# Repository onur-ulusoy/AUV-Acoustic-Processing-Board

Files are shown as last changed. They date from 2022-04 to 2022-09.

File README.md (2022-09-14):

# Acoustic Processing Board (APB) Hardware

The Acoustic Processing Board (APB) is a specialized hardware project devoted to processing underwater acoustic signals, captured via hydrophones. This repository houses the electronic design and hardware specifications needed to construct or adapt the APB. Serving as a crucial tool for underwater exploration, navigation, and communication, the APB stands as a testament to innovative engineering solutions. This project is developed for ITU AUV Team.

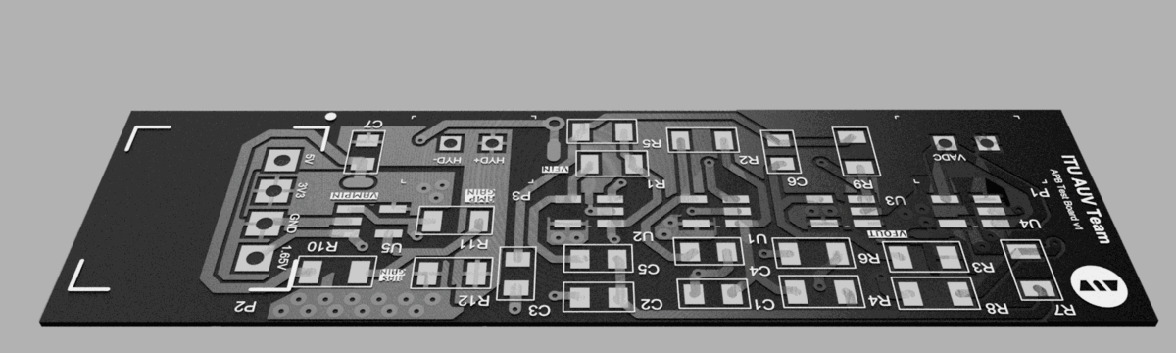
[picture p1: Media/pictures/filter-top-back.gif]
filter-board
<picture>    </picture>

<p align="center"><em >APB Filter Test Board</em></p>

<picture>   dash </picture>

<p align="center">
    <a href="https://auv.itu.edu.tr/">
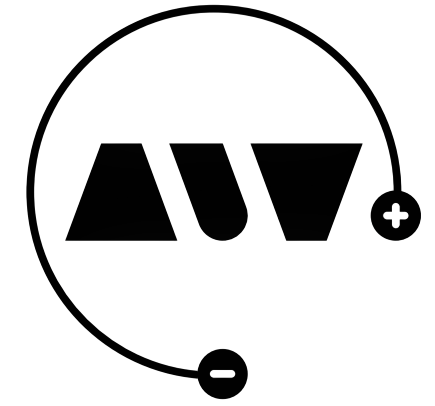
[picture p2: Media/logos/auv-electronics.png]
        
    </a>
</p>

<p align="center"><em >AUV Electronics 2022</em></p>

<picture>   dash </picture>

<p align="center">
    <a href="https://auv.itu.edu.tr/">
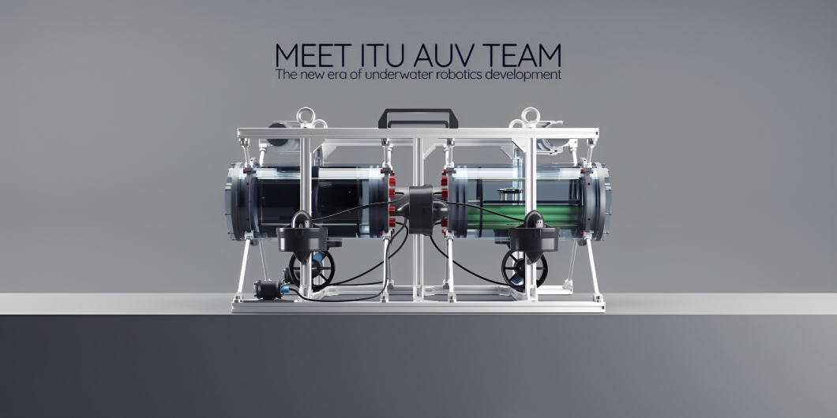
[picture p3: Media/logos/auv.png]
        
    </a>
</p>

<picture>   dash </picture>

<p align="center">
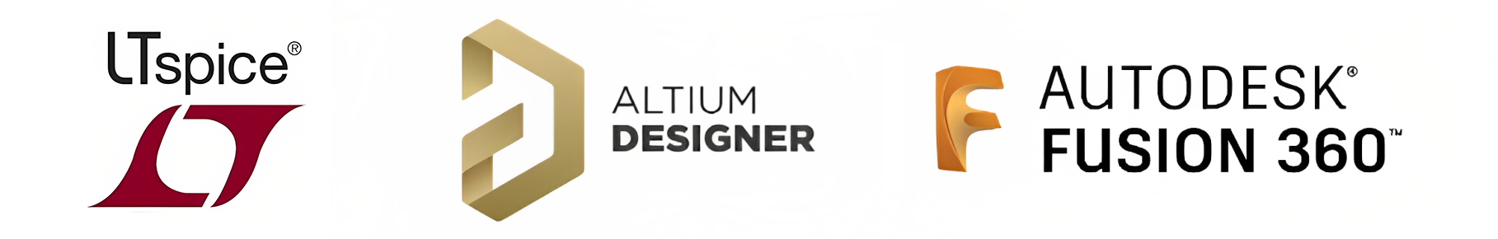
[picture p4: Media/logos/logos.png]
    
</p>

<picture>   dash </picture>

## Table of Contents
- [Acoustic Processing Board (APB) Hardware](#acoustic-processing-board-apb-hardware)
  - [Table of Contents](#table-of-contents)
  - [Project Description](#project-description)
  - [Electronics Design](#electronics-design)
    - [Hydrophone Biasing](#hydrophone-biasing)
    - [Pre-Amplification](#pre-amplification)
    - [6 Pole Butterworth Bandpass Filter](#6-pole-butterworth-bandpass-filter)
    - [Analog Power Supply](#analog-power-supply)
    - [ADC Buffering](#adc-buffering)
  - [Simulation](#simulation)
  - [Filter Test Board](#filter-test-board)
    - [Layer Structure](#layer-structure)
    - [Manufacturing](#manufacturing)
  - [Digital Part](#digital-part)
  - [Technologies Used](#technologies-used)
  - [License](#license)
  - [Project Timeline](#project-timeline)
  - [Gallery](#gallery)

## Project Description

The Acoustic Processing Board (APB) is a pivotal development in the field of Autonomous Underwater Vehicles (AUVs), designed to accurately detect the positions of underwater objects. To optimize performance, APB is split into two distinct parts: an analog PCB and a digital PCB.

The focus of this repository is the analog PCB, which primarily serves as a bandpass filter for frequencies between 25 and 40kHz. This PCB is designed to filter incoming signals from hydrophones before they are passed onto the digital component of the APB. The board was meticulously designed and simulated using LTspice software, featuring components from Analog Devices. The physical layout of the PCB was then accomplished using Altium Designer.

In addition to the analog PCB, there is a complementary digital PCB. This board is responsible for processing the filtered signals from three hydrophones to determine the location of objects underwater. It employs Fast Fourier Transform (FFT) algorithms for signal processing, and is powered by an STM32 microcontroller.

In the interest of thorough testing and performance optimization, the first iteration of the filter PCB was designed for a single hydrophone. This approach enables focused testing on the filtering capabilities, allowing for incremental improvements and fine-tuning of the board's performance before scaling to a three-hydrophone system.

The APB is a testament to innovative design, offering a unique approach to signal processing for AUVs. It represents a significant contribution to our understanding and exploration of underwater environments. We encourage you to explore the repository, understand the design, and contribute to the ongoing development of this cutting-edge technology.

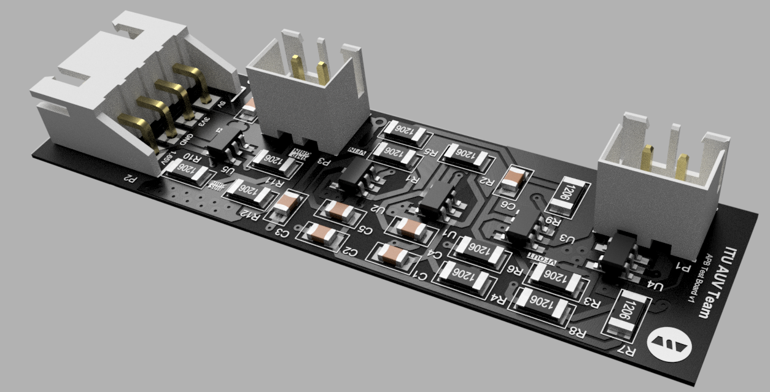
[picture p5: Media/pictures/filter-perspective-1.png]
filter-board
<picture>    </picture>

## Electronics Design

The APB Analog's design is a combination of intricate electronic engineering concepts and high-precision layout work. For an in-depth understanding of its composition, be sure to check the [Full schematics](/LTSpice_Simulation/Full%20Schematic.pdf) and [PCB Schematic Sheets](/Schematic%20Sheets/) These documents not only delineate the arrangement and interconnectivity of the board's components, but also offer insightful details about their specific roles and functionalities. Whether you're interested in the bandpass filtering process, power distribution, or the input/output interfaces, the schematic sheets hold the key to understanding the APB Analog's operational architecture.

### Hydrophone Biasing 

Hydrophone biasing is the first stage in our APB design, and it's vital to the overall functionality of the system. For each of the three hydrophones, a Vhyd- and Vhyd+ and Vcc are the inputs, while Vampin is the output. Importantly, Vhyd- is grounded. This arrangement ensures the correct biasing of the hydrophones, setting the correct operating point for each device and allowing for the effective conversion of underwater acoustic signals into electrical signals.

<p align="center">
    <a>
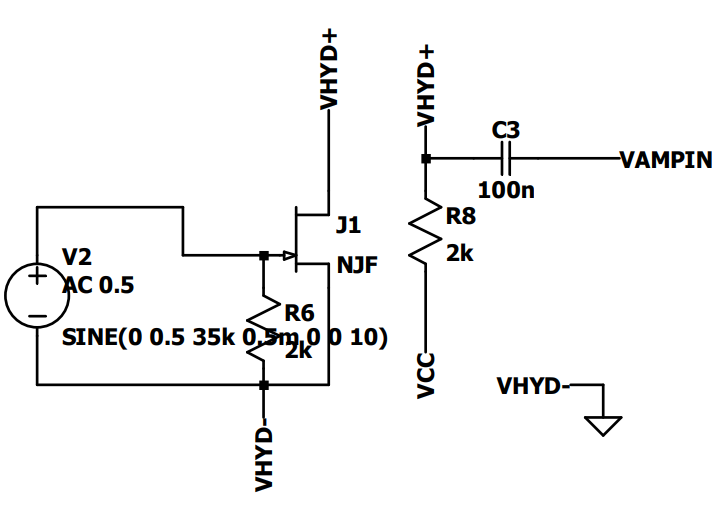
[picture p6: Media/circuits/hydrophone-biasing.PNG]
        
    </a>
</p>

### Pre-Amplification

The pre-amplification stage is another essential component of our APB design, ensuring that the electrical signals produced by the hydrophones are amplified adequately for further processing. This stage also employs three separate units, one for each hydrophone. Vampin is used as the input, while Vfin serves as the output. The pre-amplifier is driven by a high precision op-amp, ensuring low-noise amplification and thereby enhancing the clarity and resolution of the captured signals.

<p align="center">
    <a>
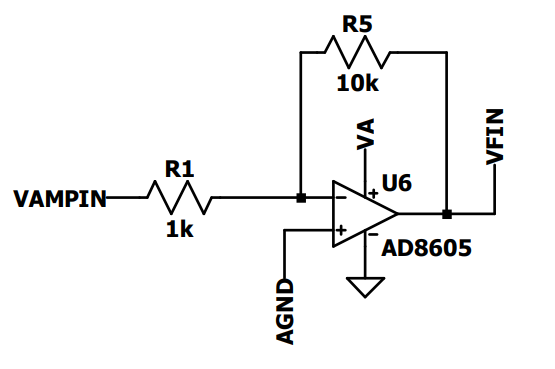
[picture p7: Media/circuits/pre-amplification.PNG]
        
    </a>
</p>

### 6 Pole Butterworth Bandpass Filter

To further process the amplified signals, we employ a 6-pole Butterworth bandpass filter. This filter is replicated three times, once for each hydrophone. The selection of this specific filter topology allows for a flat frequency response in the passband, and a fast roll-off rate, making it highly suitable for our signal processing needs. Appropriate capacitor and resistor values were determined using Analog Devices' application notes. The filter takes Vfin as an input and outputs a filtered signal, Vfout. Each operational amplifier in this stage is referenced with Agnd, which is supplied by the analog power supply circuit.

<p align="center">
    <a>
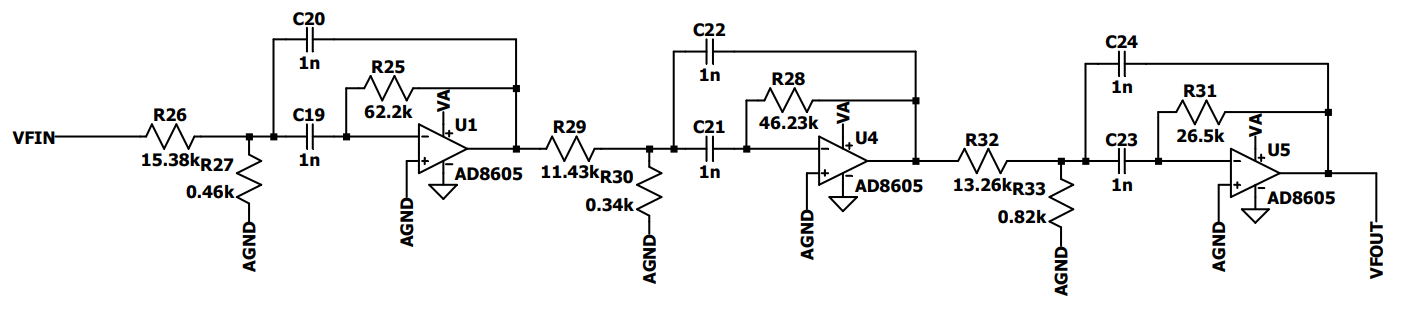
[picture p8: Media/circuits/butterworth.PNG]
        
    </a>
</p>

### Analog Power Supply

The analog power supply is an integral part of our design. Va is the input, and Agnd is the output. This unit provides the necessary power for all analog sections of the APB. Va and Agnd form the positive and negative poles of the op-amp in the other circuits. By generating a stable and low-noise power supply, this circuit ensures that the operational amplifiers and other analog components function optimally, minimizing signal distortion and maintaining high signal-to-noise ratios.

<p align="center">
    <a>
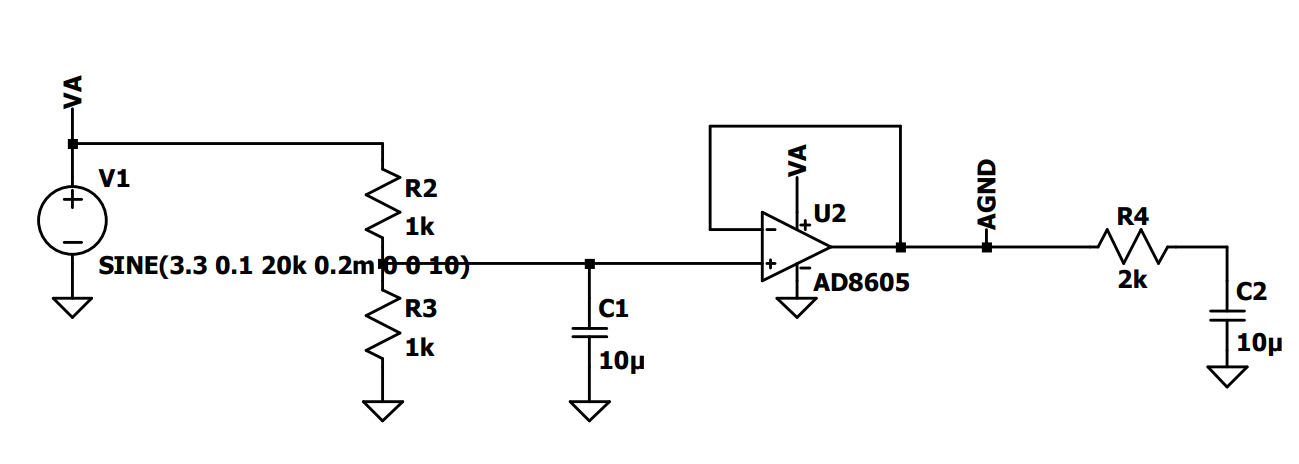
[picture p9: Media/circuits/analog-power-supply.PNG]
        
    </a>
</p>

### ADC Buffering

ADC buffering serves as the bridge between the analog and digital domains of our APB design. This stage, replicated three times for each hydrophone, takes the filtered signal, Vfout, as input and provides Vadc as output. The buffer, a unity gain amplifier (1x amp), plays a critical role in this system. Its purpose is to isolate the preceding stages from the ADC load. This isolation prevents any impedance mismatch that could degrade the signal quality. By using a buffer, we ensure that the signals processed by the ADC reflect as closely as possible the filtered signals from the bandpass filter stage, enabling accurate digital representation of the original acoustic signals.

<p align="center">
    <a>
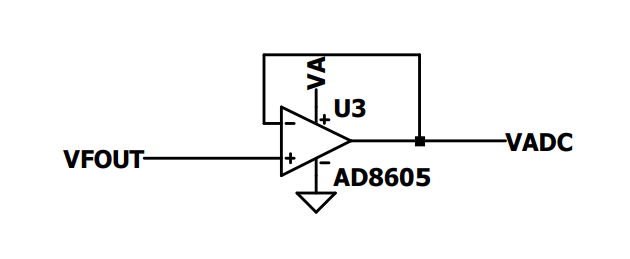
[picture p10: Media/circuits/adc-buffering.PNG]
        
    </a>
</p>

## Simulation

The APB analog subsystem was thoroughly simulated using LTspice, a high-performance SPICE simulator. LTspice offers a variety of capabilities, including enhanced SPICE and an integrated waveform viewer, making it a powerful tool for circuit analysis.

The simulation process involved the use of specific op-amps from Analog Devices. This choice of op-amps was driven by their favorable characteristics, such as low noise, high precision, and their performance within the frequency band of interest.

To ascertain the effectiveness of our 6-pole Butterworth bandpass filter design, we carried out frequency domain analysis. The results are demonstrated in the Bode plot below. As can be seen, the filter provides a passband for frequencies between 25 and 40 kHz, while attenuating frequencies outside this band. This frequency range was chosen specifically to match the operating range of the hydrophones and the acoustic signals they receive.

The simulation results validate the performance of the filter design and provide confidence in its ability to function as intended in the real-world application.

<p align="center">
    <a>
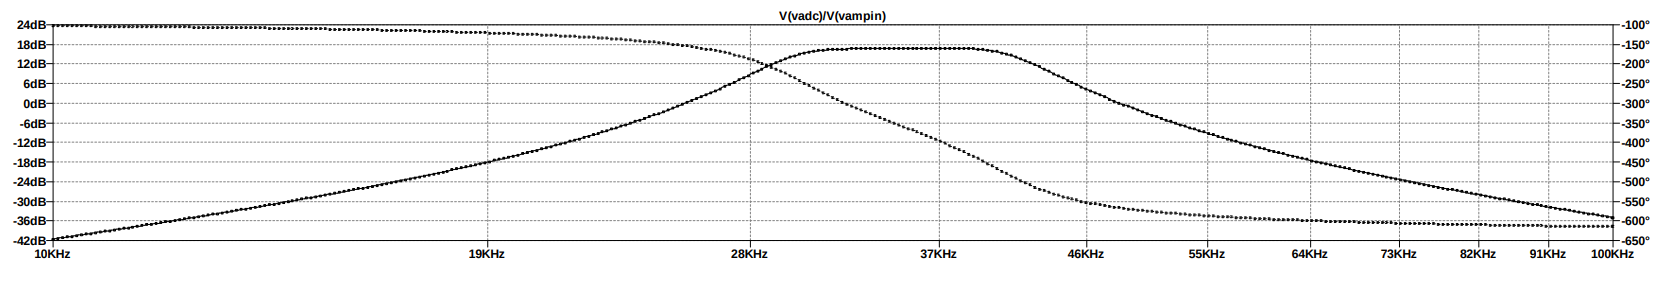
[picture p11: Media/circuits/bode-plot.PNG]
        
    </a>
</p>

## Filter Test Board

As part of our development and testing process, we designed a standalone PCB specifically for testing the performance of the filter stage and associated circuits. This board, known as the Filter Test Board, includes only the Butterworth filter, ADC buffering, and pre-amplification circuits, all for just a single hydrophone. 

The Filter Test Board contains crucial components from our original APB analog design that we aimed to test in isolation. We included the Butterworth filter stage, which is the centerpiece of our acoustic processing, to evaluate its frequency response and signal attenuation properties. The Pre-Amplification stage is also included, as it plays a crucial role in enhancing the signals coming from the hydrophone. Additionally, the ADC Buffering stage is incorporated into it. This stage is crucial for isolating the ADC load from the preceding stages, thereby preserving signal integrity. By focusing on these critical parts, the Filter Test Board allows us to verify the operation and performance of the main building blocks of our system without the interference of other elements. As a summary, It is basically includes cruical parts to process one hydrophone signal.

To aid in testing, we've added test points at key output locations like Vampin or Vfin as you can see in the below pcb picture, allowing for easy hook-up of measurement equipment such as oscilloscopes or signal generators. This way, we can inject signals and observe the system's response directly. We gave some voltages such as 1.65V directly to get rid of some power circuits.

Furthermore, we've chosen to use industrial-grade connectors for power supply and signal output. These connectors provide robust, reliable connections, crucial for both testing and eventual deployment.

The schematic diagrams for the Filter Test Board are available in the repository at [PCB Schematic Sheets](/Schematic%20Sheets/). Here, you'll find the full details of the circuits on the test board, providing a wealth of information for understanding and troubleshooting.

Below is top view of the Filter Test Board:

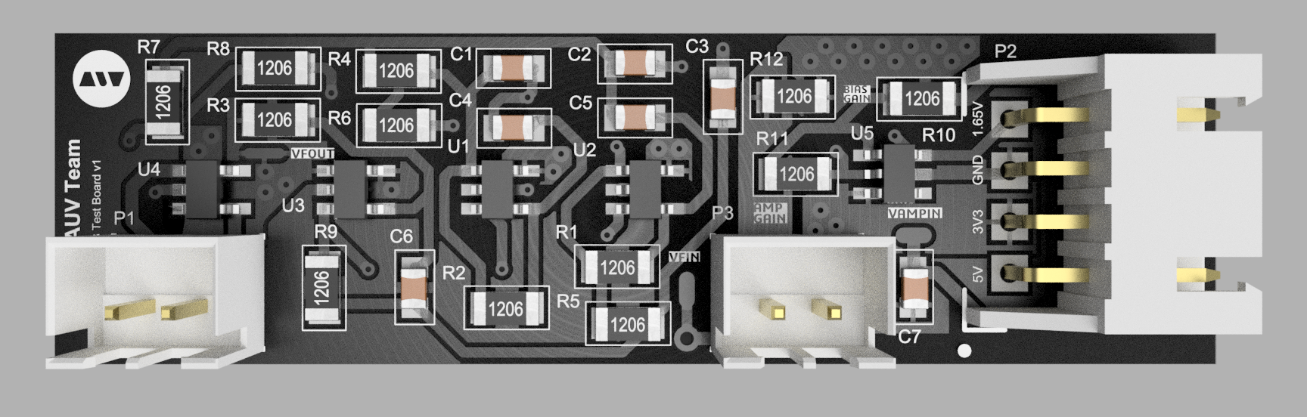
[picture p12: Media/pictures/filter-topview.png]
filter-board
<picture>    </picture>

### Layer Structure

This test version of the APB Analog PCB utilizes a two-layer structure, which has been chosen to simplify the initial stages of testing and troubleshooting. Once the test phase is complete and the design is deemed satisfactory, a transition to a four-layer PCB will take place for the original design. The change in layers not only accommodates the increased complexity of handling signals from three hydrophones simultaneously but also provides better noise isolation and improved signal integrity. Our filter test board's layers can be seen below.

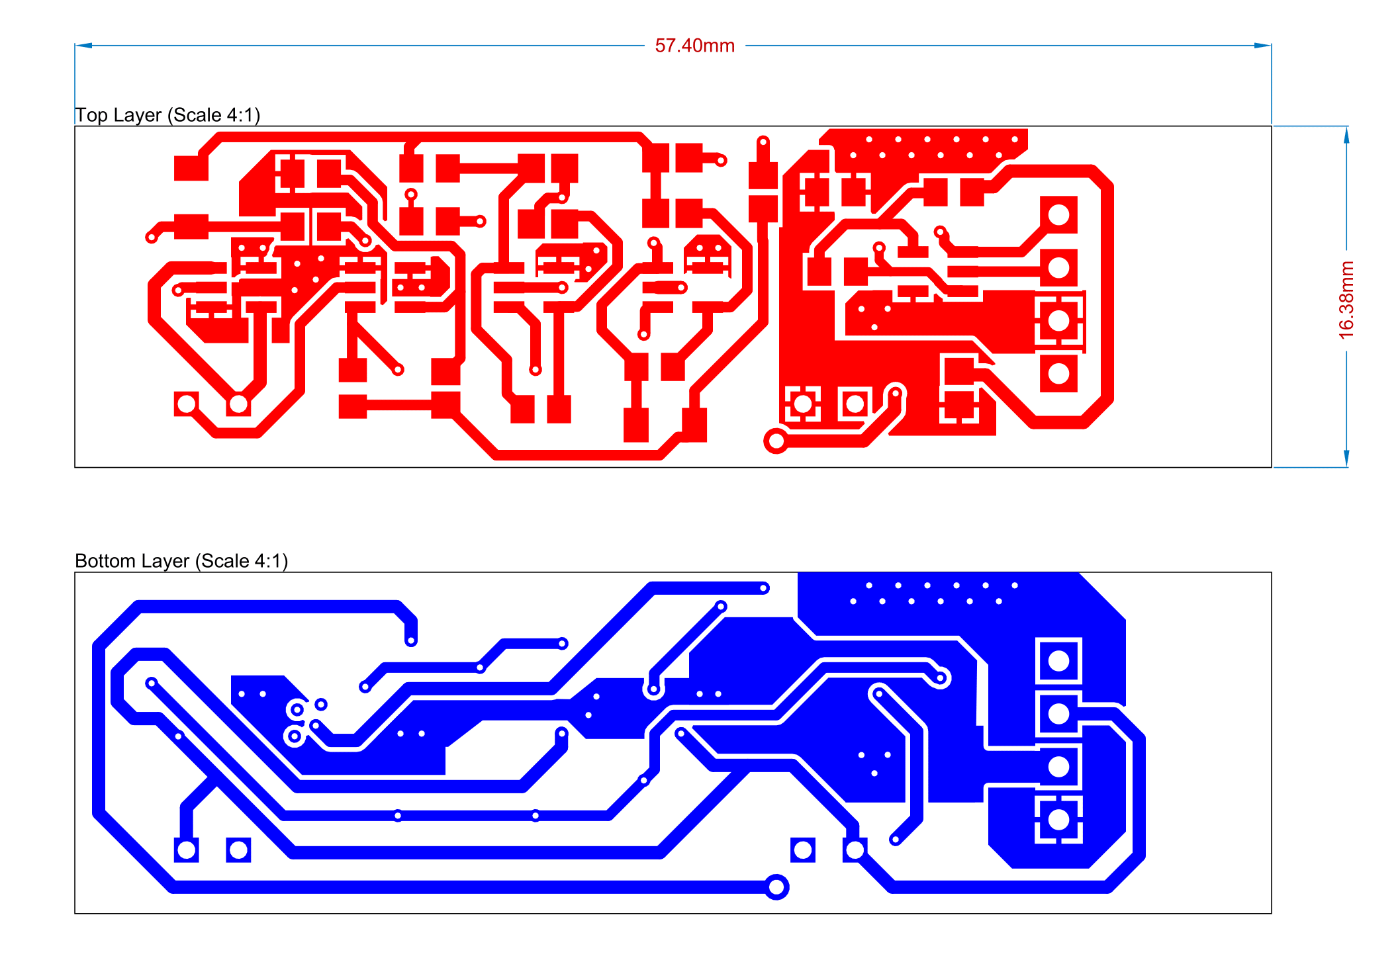
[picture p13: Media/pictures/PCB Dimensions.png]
<picture>    </picture>

To understand the depth of the board structure, component placement, and routing of traces, you can check out the [PCB file](/APB_Filter_Test_Board.PrjPcb). It offers a visual representation of the board, aiding in a better understanding of how the circuit's design translates into the physical realm. Keep in mind that this transition from a two-layer board to a four-layer one marks a critical milestone in the evolution of the APB project, embodying the growth from a test concept to a fully-realized, operational piece of hardware.

### Manufacturing

In order to ensure that our Filter Test Board design meets the specific manufacturing specifications of our chosen PCB manufacturer, we have employed the Design Rule Check (DRC) feature in Altium Designer. You can check the detailed report of this rule verification in the output files directory. 

The necessary Gerber files, which include the comprehensive manufacturing details needed to transform our electronic design into a tangible board, are compiled in the [Output](/Output%20Files/) directory.

To date, we have prototyped the Filter Test Board with our manufacturing partner, JLC PCB. Using the invaluable feedback and insights acquired from each iteration, we have continuously refined and improved the design, ensuring it's prepared for rigorous testing and eventual integration into the full Acoustic Processing Board system.

Below you can see some of the pictures of PCBs we manufactured:

<p align="center">
    <a>
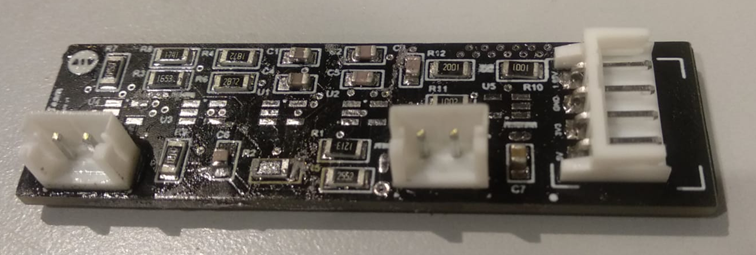
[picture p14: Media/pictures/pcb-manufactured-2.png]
        
    </a>
</p>

<p align="center">
    <a>
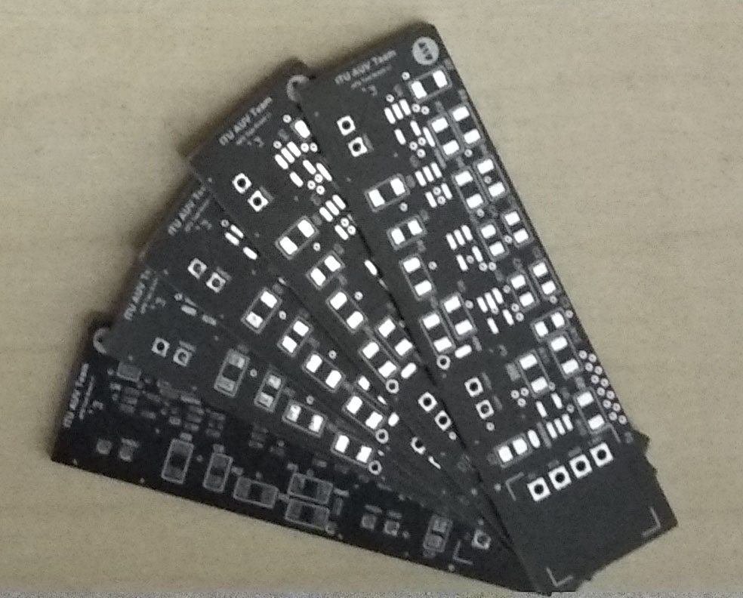
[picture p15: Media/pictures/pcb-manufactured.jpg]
        
    </a>
</p>

## Digital Part

The Digital Part represents the second crucial stage of the Acoustic Processing Board (APB). After the Analog Part processes the signals from the hydrophones, it's the responsibility of the Digital Part to receive these analog signals, evaluate them, and ultimately pinpoint the location of the acoustic source underwater.

One of the core operations conducted by the Digital Part involves Fast Fourier Transforms (FFTs). FFTs are a fundamental algorithm in signal processing and analysis, serving to convert a signal from the time domain (where each point represents amplitude at a specific time) into the frequency domain (where each point represents amplitude at a specific frequency). In the context of our APB, we use FFTs to identify the dominant frequencies present in the signals received from the hydrophones, which, when triangulated, can help determine the location of the underwater sound source.

The computational demands of these FFT operations are shouldered by an STM32H743 microcontroller. This powerful microcontroller is well-equipped to handle the processing needs of our board, boasting impressive capabilities, such as handling complex FFT operations and processing data from multiple hydrophones concurrently.

As of the time you're reading this, the development of the Digital Part is still underway. We are committed to achieving a robust, reliable digital signal processing system that effectively complements the analog processing capabilities of the APB. Stay tuned for updates as we continue to progress in this exciting project.

## Technologies Used

- **LTSpice:** At the outset of our design process, we used LTSpice, a high-performance SPICE simulator, for schematic capture and waveform viewer. This tool allowed us to simulate and analyze the behavior of our circuit designs, including the hydrophone biasing, pre-amplification, and filtering stages.

- **Analog Devices Web Applications:** To calculate the optimal values for our 6-Pole Butterworth Bandpass Filter components, we made use of the web applications provided by Analog Devices. These tools were indispensable in ensuring the correct operation of our filters, which play a critical role in the overall performance of the APB.

- **Altium Designer:** Our primary tool for crafting the complex layout of the PCBs was Altium Designer. Its powerful capabilities and intuitive interface allowed us to efficiently design, validate, and prepare the board's electronic components for manufacturing. Its extensive features facilitated the smooth handling of multi-layer board designs.

- **Eagle:** As an alternative to Altium Designer, we also used Autodesk Eagle for some aspects of the design process. Eagle offered us a simpler, more streamlined interface for initial design and testing stages, before transitioning to the more robust Altium Designer for finalizing the intricate multi-layer layout.

- **Fusion 360:** To manage the mechanical design and rendering of the APB, we used Autodesk Fusion 360. This powerful CAD/CAM tool not only allowed us to visualize and perfect the physical design of the board but also helped us ensure its compatibility within the AUV. The integration capabilities of Fusion 360 also facilitated seamless coordination with the mechanical team.

## License



This repository contains the design and documentation for the AUV Acoustic Processing Board, a project by the ITU AUV Team Electonics 2022.

**Licensor:** ITU AUV Team 2022 Electronics

This work is licensed under a [Creative Commons Attribution-NonCommercial-ShareAlike 4.0 International License](http://creativecommons.org/licenses/by-nc-sa/4.0/). You can view the full terms of the license in the [LICENSE](./LICENSE) file in this repository.

**Please note:** When using this project, you must give appropriate credit, including a link to the original GitHub repository: [https://github.com/onur-ulusoy/AUV-Acoustic-Processing-Board](https://github.com/onur-ulusoy/AUV-Acoustic-Processing-Board)

## Project Timeline

This Acoustic Processing Board (APB) project, a significant contribution to the 2022 Electronics Team of ITU AUV (Istanbul Technical University's Autonomous Underwater Vehicle), spanned from December 2021 to August 2022. 

In the initial design and simulation stages of the project, Onur Ulusoy and Sencer Yazıcı diligently worked to create an effective system for processing signals from underwater hydrophones. Their efforts involved comprehensive electronic design and meticulous simulation using LTSpice and Analog Devices' applications. 

Once the design was validated through simulation, the next stage of the project involved the physical realization of the APB. The Filter Test PCB, an essential component of the project, was designed, have manufactured, and typeset by Onur Ulusoy. This crucial testing PCB was brought to life using Altium Designer, with the manufacturing process carried out by JLCPCB. 

While the project was ongoing, thorough documentation was maintained by Onur Ulusoy. His efforts provided an accurate and detailed record of the project, documenting key design decisions, simulation results, and changes made during the PCB design and testing stages. 

As of the current timeline, the Digital Part of the APB, which is designed to receive and analyze the processed signals, is not yet completed. However, the successful development and testing of the APB's analog parts mark significant milestones towards the final goal. 

We are grateful for the invaluable guidance provided by Sencer Yazıcı throughout the development process. His expertise and mentorship played a crucial role in the success of this project. 

Throughout the duration of the Acoustic Processing Board (APB) project, we utilized Trello as our primary project management tool. Trello's intuitive interface and flexible features allowed us to plan, track, and coordinate our tasks effectively. By creating distinct cards for different tasks and using lists to represent different stages of our workflow, we were able to maintain a clear overview of our progress at all times. 

## Gallery

For a visual tour of the APB Filter Test Board PCB, you can explore our [gallery](https://onur-ulusoy.github.io/AUV-Acoustic-Processing-Board/Media/gallery.html). Here you'll find detailed images showcasing the design and implementation of the board.

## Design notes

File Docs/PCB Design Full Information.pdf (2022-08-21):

## 6 Pole Butterworth Bandpass Filter

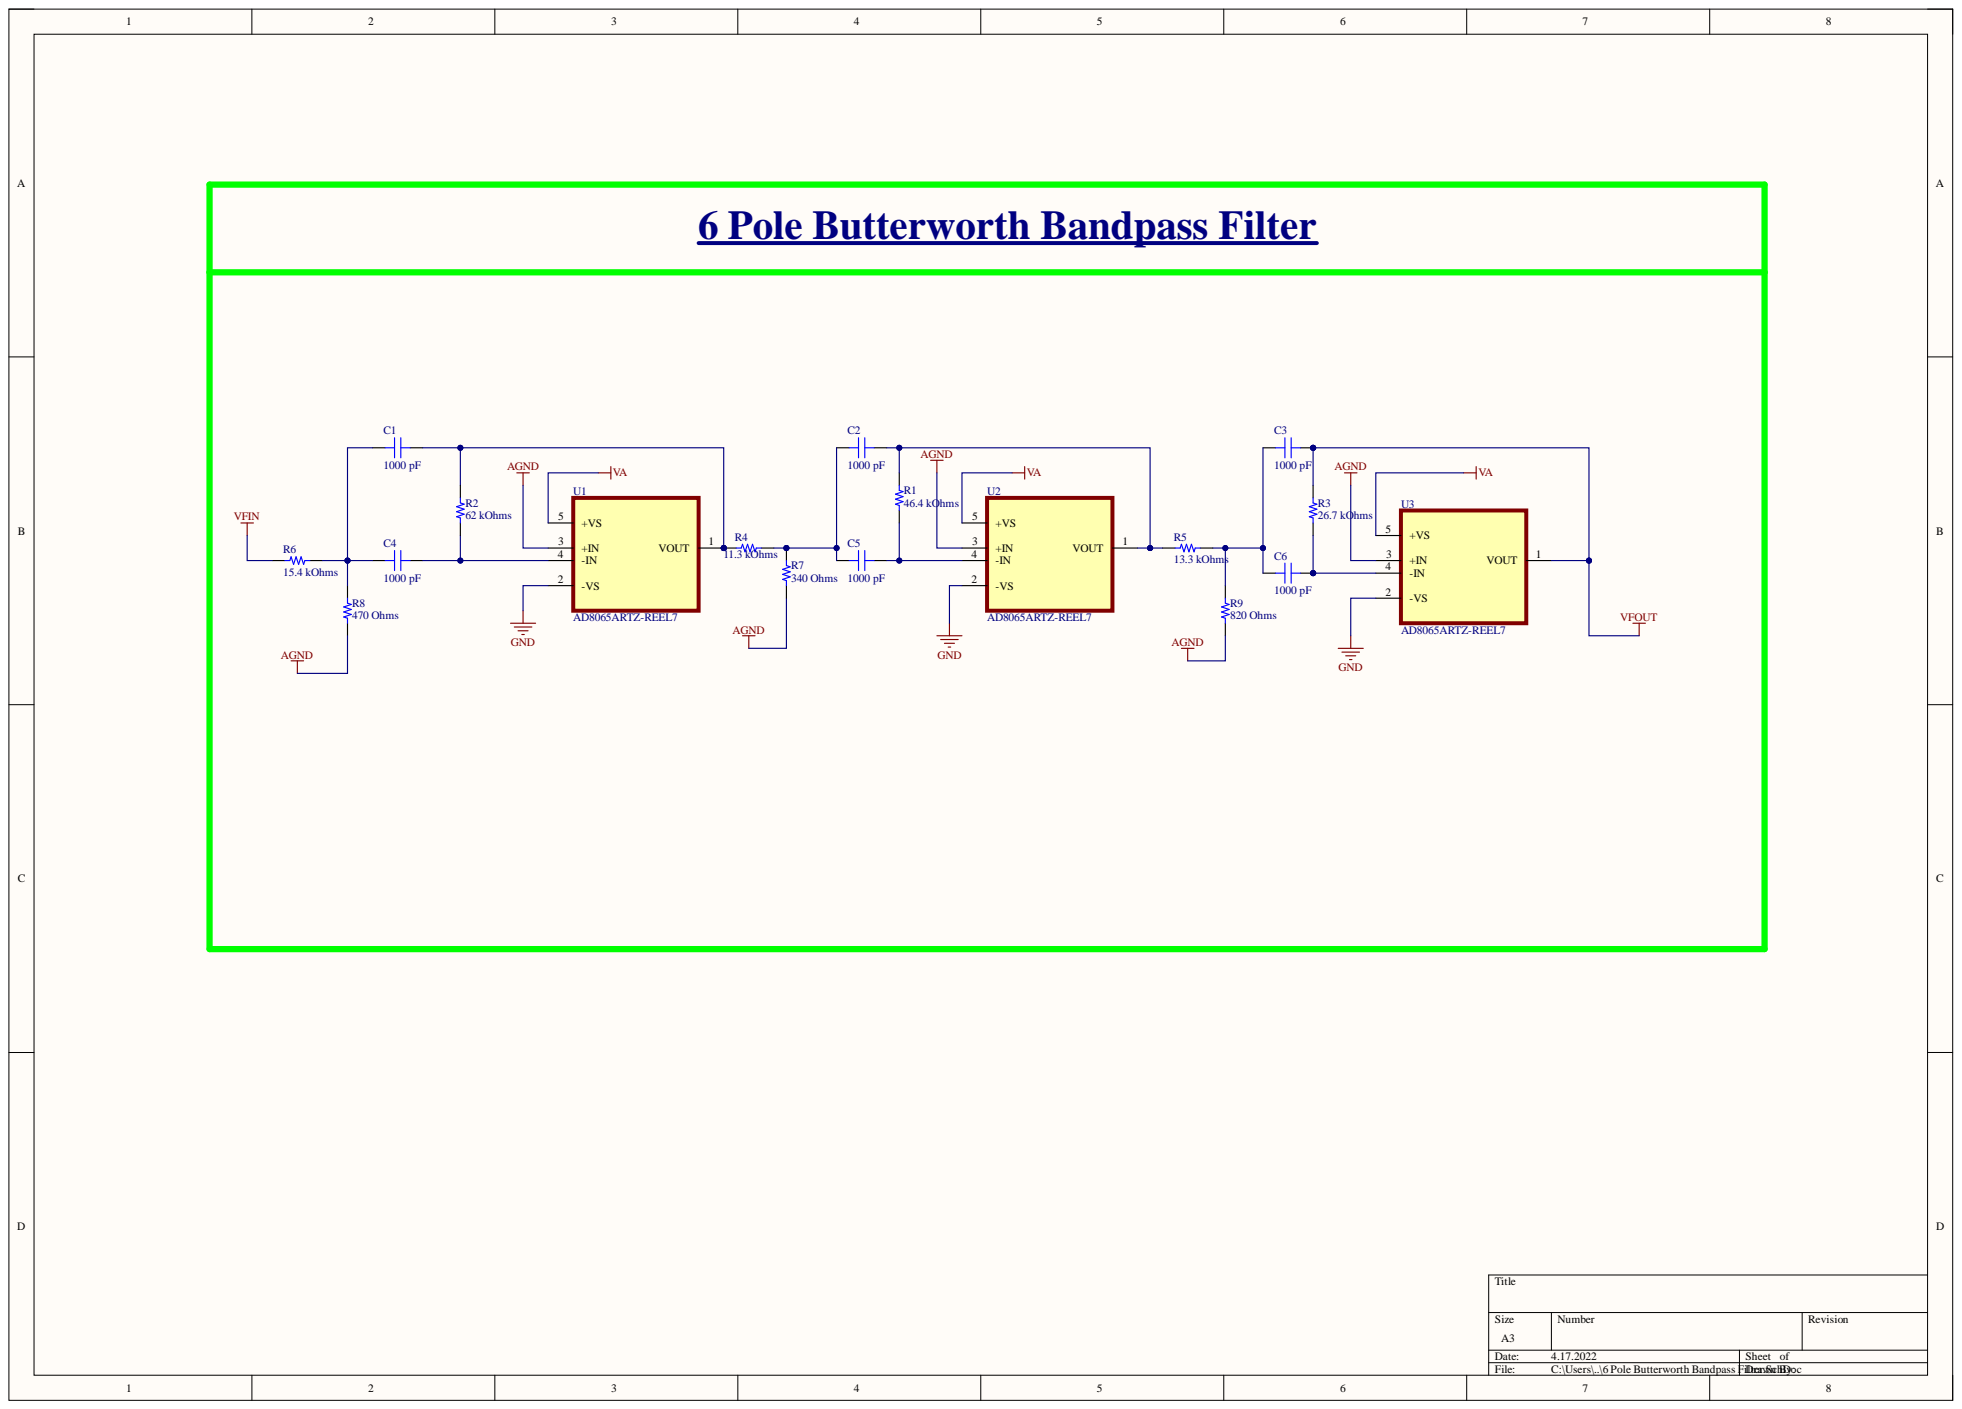
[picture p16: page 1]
Numbe; Revi; Dat; Sheet of; ser; \..\6 Pole; But; ter; wor; Bandpas; VFO; VFI; 11.3 kOhm; 15.4 kOhm; Ohm; 46.4 kOhm; 26.7 kOhm; 13.3 kOhm; 62 kOhm

s FiDltreraw.SchD n By:oc

# ADC Buffering

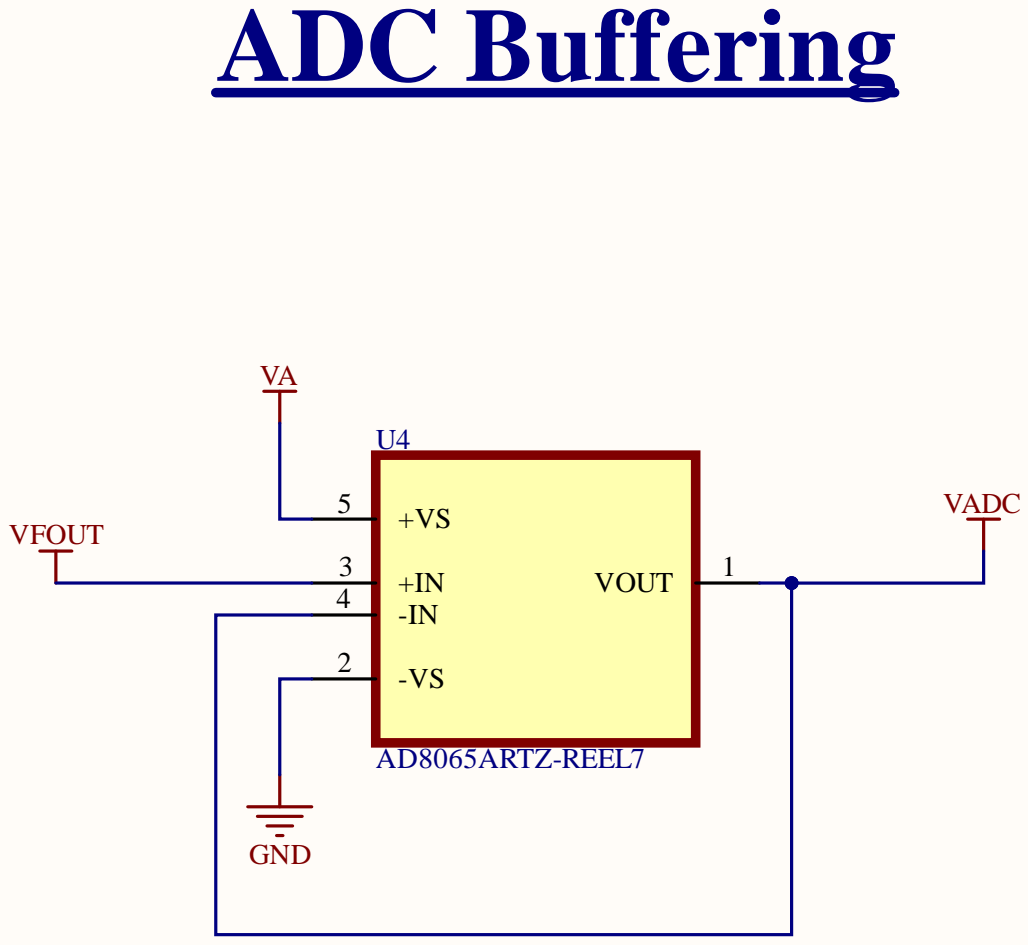
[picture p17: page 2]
Title; Size; Number; Revision; Date:; Sheet of; File:; C:\Users\..\ADC Buffering.SchDoc; Drawn By:; VOUT; AD8065ARTZ-REEL7; VFOUT; GND; VADC; PIU401; PIU402; PIU403; PIU404; PIU405; COU4

# Input-Output

### Pre Amp

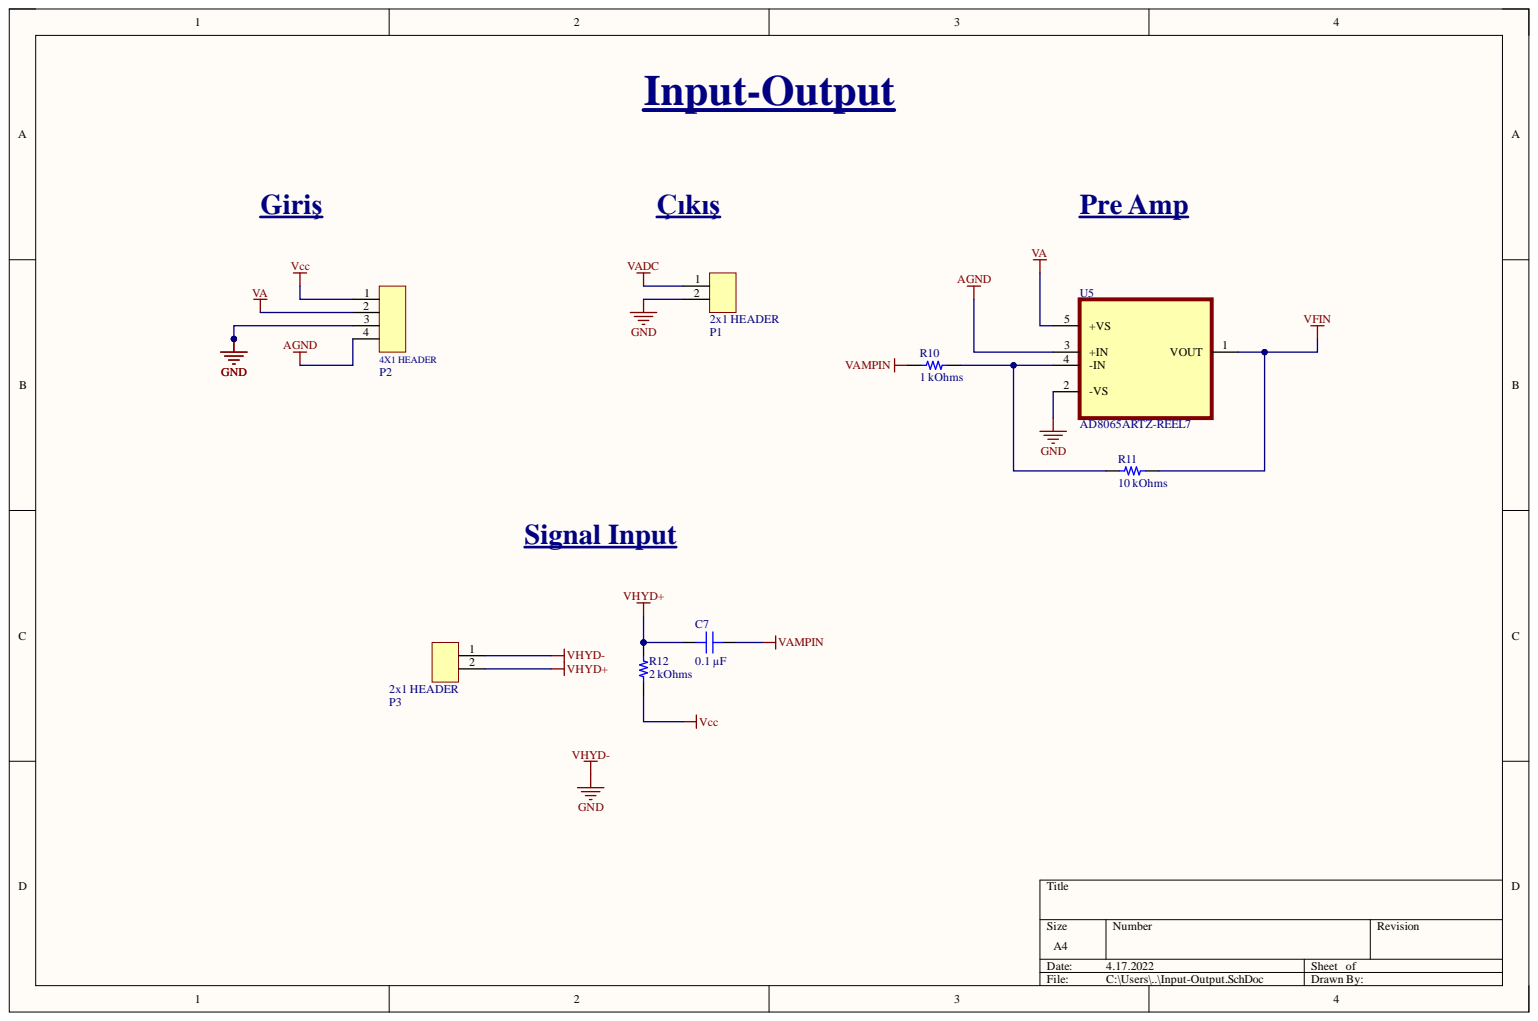
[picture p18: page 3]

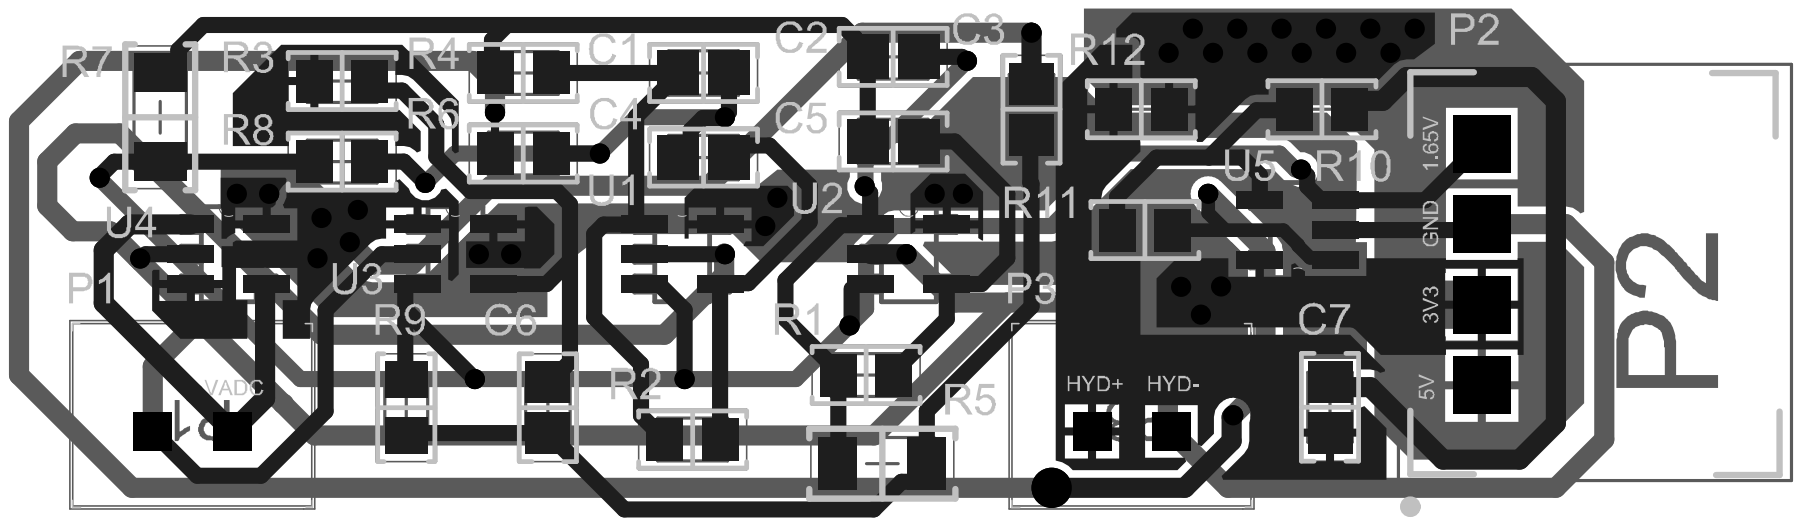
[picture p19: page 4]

Comment | Description | Designator | Footprint | LibRef | Quantity
1000 pF | CAP CER 1000PF 100V C0G 0805 | C1, C2, C3, C4, C5, C6 | CAP 0805_2012 | C2012C0G2A102J060 AA | 6
0.1 µF | CAP CER 0.1UF 50V X7R 0805 | C7 | CAP 0805_2012 | CC0805MRX7R9BB10 4 | 1
WIRE-TO BOARD WAFER, 2.5MM, 2 CO | Connector Header Through Hole 2 position 0.098" (2.50mm) | P1, P3 | 51025-02-0100-01 | 51025-02-0100-01 | 2
WIRE-TO BOARD HEADER, 2.5MM, 4 C | Wire-to Board Header, 2.5MM, 4 C | P2 | 51125-04-0200-01 | 51125-04-0200-01 | 1
46.4 kOhms | RES SMD 46.4K OHM 0.5% 1/8W 0805 | R1 | RES 0805_2012 | RT0805DRE0746K4L | 1
62 kOhms | RES SMD 62K OHM 0.1% 1/10W 0805 | R2 | RES 0805_2012 | CPF0805B62KE1 | 1
26.7 kOhms | RES SMD 26.7K OHM 1% 1/8W 0805 | R3 | RES 0805_2012 | ERJ-6ENF2672V | 1
11.3 kOhms | RES 11.3K OHM 1% 1/4W 0805 | R4 | RES 0805_2012 | RK73H2ATTD1132F | 1
13.3 kOhms | RES 13.3K OHM 1% 1/4W 1206 | R5 | RES 1206_3216 | RK73H2BTTD1332F | 1
15.4 kOhms | RES SMD 15.4K OHM 1% 1/8W 0805 | R6 | RES 0805_2012 | ERJ-6ENF1542V | 1
340 Ohms | RES SMD 340 OHM 1% 1/4W 1206 | R7 | RES 1206_3216 | ERJ-8ENF3400V | 1
470 Ohms | RES 470 OHM 1% 1/3W 0805 | R8 | RES 0805_2012 | CRGP0805F470R | 1
820 Ohms | RES 0805 820R 5% 125MW TC200 LOW | R9 | RES 0805_2012 | CR0805-JW-821EPF | 1
1 kOhms | RES SMD 1K OHM 5% 1/3W 0805 | R10 | RES 0805_2012 | CRGH0805J1K0 | 1
10 kOhms | RES 10K OHM 0.5% 1/8W 0805 | R11 | RES 0805_2012 | RNCF0805DTE10K0 | 1
2 kOhms | RES SMD 2K OHM 1% 0.4W 0805 | R12 | RES 0805_2012 | RCS08052K00FKEA | 1
AD8065ARTZ-REEL7 | Voltage Feedback Amplifier 1 Circuit Rail-to-Rail SOT-23-5 | U1, U2, U3, U4, U5 | SOT95P290X145-5N | AD8065ARTZ-REEL7 | 5

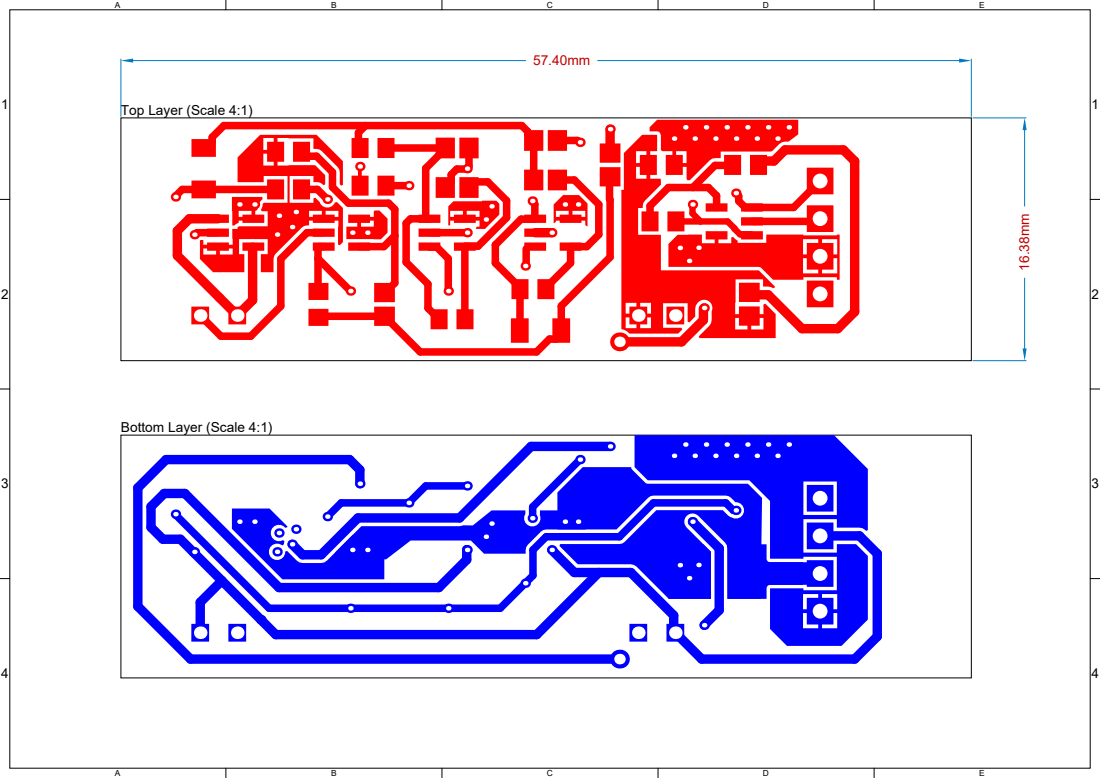
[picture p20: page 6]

Top Layer (Scale 4:1)

Bottom Layer (Scale 4:1)

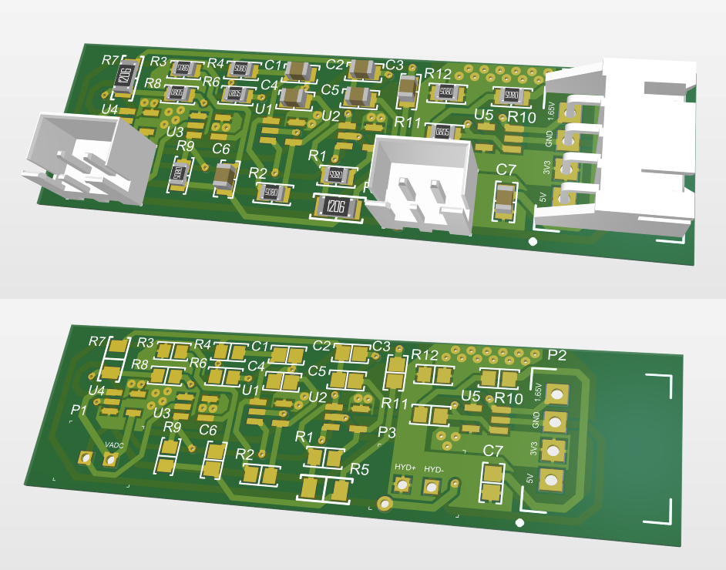
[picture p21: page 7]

### Dirençler

11.3k (Paket: 0805)

Digikey:

https://www.digikey.com/en/products/detail/koa-speer-electronicsinc/RK73H2ATTD1132F/10233627 (https://www.digikey.com/en/products/detail/koa-speer-electronics-inc/RK73H2ATTD1132F/10233627)

Özdisan:

https://ozdisan.com/passive-components/resistors/smt-smd-and-chip-resistors/0805S8F1132T5E

R340 (Paket: 1206)

Digikey:

https://www.digikey.com/en/products/detail/panasonic-electronic-components/ERJ-8ENF3400V/88773 (https://www.digikey.com/en/products/detail/panasonic-electronic-components/ERJ-8ENF3400V/88773)

Özdisan:

https://ozdisan.com/passive-components/resistors/smt-smd-and-chip-resistors/1206S4F3400T5E

62k (Paket: 0805)

Digikey:

https://www.digikey.com/en/products/detail/te-connectivity-passiveproduct/CPF0805B62KE1/2382068 (https://www.digikey.com/en/products/detail/te-connectivity-passive-product/CPF0805B62KE1/2382068)

Özdisan:

https://ozdisan.com/passive-components/resistors/smt-smd-and-chip-resistors/0805S8J0623T5E

15.4k Paket: (0805)

Digikey:

https://www.digikey.com/en/products/detail/ERJ-6ENF1542V/P15.4KCCT-ND/119315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 (https://www.digikey.com/en/products/detail/ERJ-6ENF1542V/P15.4KCCT-ND/119315?curr=usd)

Özdisan:

https://ozdisan.com/passive-components/resistors/smt-smd-and-chip-resistors/0805S8F1542T5E

R470 (Paket: 0805)

Digikey:

https://www.digikey.com/en/products/detail/CRGP0805F470R/A130473CT-ND/8578305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 (https://www.digikey.com/en/products/detail/CRGP0805F470R/A130473CT-ND/8578305?curr=usd)

Özdisan:

https://ozdisan.com/passive-components/resistors/smt-smd-and-chip-resistors/0805S8J0471TDE

46.4k (Paket: 0805)

Digikey:

https://www.digikey.com/en/products/detail/yageo/RT0805DRE0746K4L/1078715

Özdisan:

https://ozdisan.com/passive-components/resistors/smt-smd-and-chip-resistors/0805S8F4642T5E

13.3k (Paket: 1206)

Digikey:

https://www.digikey.com/en/products/detail/koa-speer-electronicsinc/RK73H2BTTD1332F/10236178 (https://www.digikey.com/en/products/detail/koa-speer-electronics-inc/RK73H2BTTD1332F/10236178)

Özdisan:

https://ozdisan.com/passive-components/resistors/smt-smd-and-chip-resistors/1206S4F1332T5E

R820 (Paket: 0805)

Digikey:

https://www.digikey.com/en/products/detail/bourns-inc/CR0805-JW-821EPF/8572952

Özdisan:

https://ozdisan.com/passive-components/resistors/smt-smd-and-chip-resistors/0805S8J0821T5E

26.7k (Paket: 0805)

Digikey:

https://www.digikey.com/en/products/detail/panasonic-electronic-components/ERJ-6ENF2672V/111557 (https://www.digikey.com/en/products/detail/panasonic-electronic-components/ERJ-6ENF2672V/111557)

Özdisan:

https://ozdisan.com/passive-components/resistors/smt-smd-and-chip-resistors/0805S8F2672T5E

1k (Paket: 0805)

Digikey:

https://www.digikey.com/en/products/detail/te-connectivity-passiveproduct/CRGH0805J1K0/2385524 (https://www.digikey.com/en/products/detail/te-connectivity-passive-product/CRGH0805J1K0/2385524)

Özdisan:

https://ozdisan.com/passive-components/resistors/smt-smd-and-chip-resistors/0805S8F1001T5E

10k (Paket: 0805)

Digikey:

https://www.digikey.com/en/products/detail/stackpole-electronics-inc/RNCF0805DTE10K0/1708247

Özdisan:

https://ozdisan.com/passive-components/resistors/smt-smd-and-chip-resistors/0805S8F1002T5E

2k (Paket: 0805)

Digikey:

https://www.digikey.com/en/products/detail/vishay-dale/RCS08052K00FKEA/5866986

Özdisan:

https://ozdisan.com/passive-components/resistors/smt-smd-and-chip-resistors/0805S8F2001T5E

### Kapasiteler

### 1 nF (Paket: 0805)

Digikey:

https://www.digikey.com/en/products/detail/C2012C0G2A102J060AA/445-2320-1-ND/789829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 (https://www.digikey.com/en/products/detail/C2012C0G2A102J060AA/445-2320-1-ND/789829?curr=usd)

Özdisan:

https://ozdisan.com/passive-components/capacitors/smt-smd-and-mlcccapacitors/CL21B102KBANNNC (https://ozdisan.com/passive-components/capacitors/smt-smd-and-mlcc-capacitors/CL21B102KBANNNC)

### 0.1 uF (Paket: 0805)

Digikey:

https://www.digikey.com/en/products/detail/CC0805MRX7R9BB104/311-4351-1-ND/8025440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 (https://www.digikey.com/en/products/detail/CC0805MRX7R9BB104/311-4351-1-ND/8025440?curr=usd)

Özdisan:

https://ozdisan.com/passive-components/capacitors/smt-smd-and-mlcccapacitors/CL21B104KCFNNNE (https://ozdisan.com/passive-components/capacitors/smt-smd-and-mlcc-capacitors/CL21B104KCFNNNE)

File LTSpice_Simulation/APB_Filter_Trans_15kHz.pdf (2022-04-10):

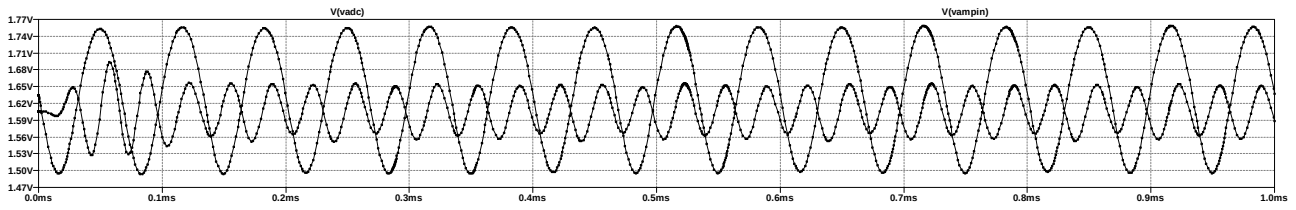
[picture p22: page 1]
V(vadc); V(vampin)

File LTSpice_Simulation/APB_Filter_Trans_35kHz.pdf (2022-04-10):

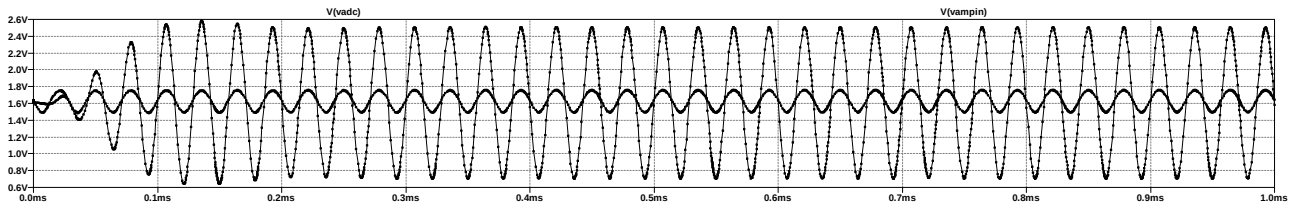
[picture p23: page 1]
V(vadc); V(vampin)

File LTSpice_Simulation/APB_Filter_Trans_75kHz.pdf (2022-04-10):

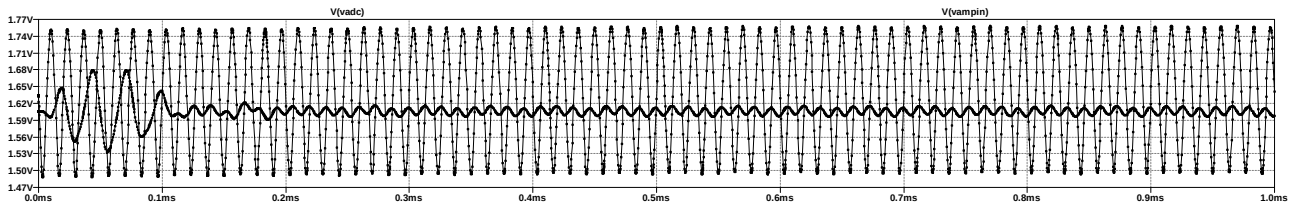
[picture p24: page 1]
V(vadc); V(vampin)

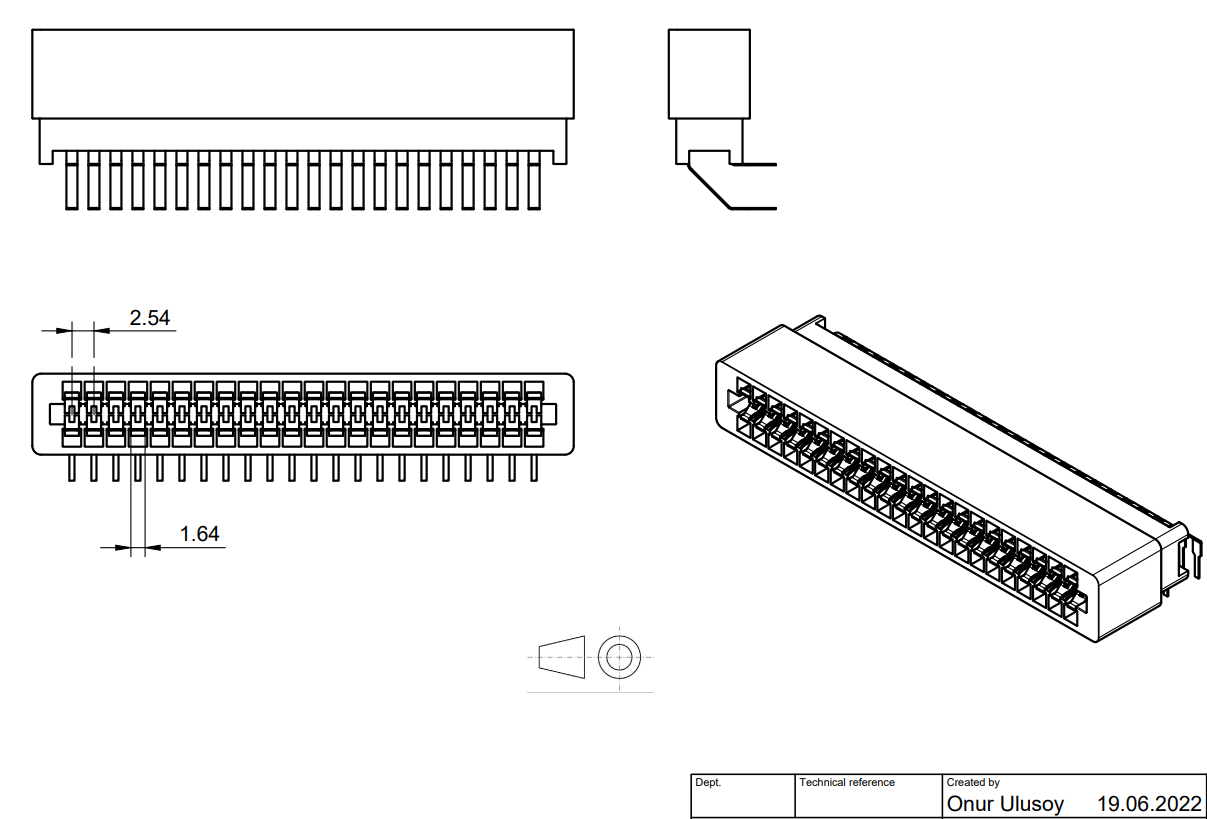
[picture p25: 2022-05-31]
Docs/EDGE PCB Connector P2.54mm 44pin 2 Rows Right Angle Drawing v3.PNG

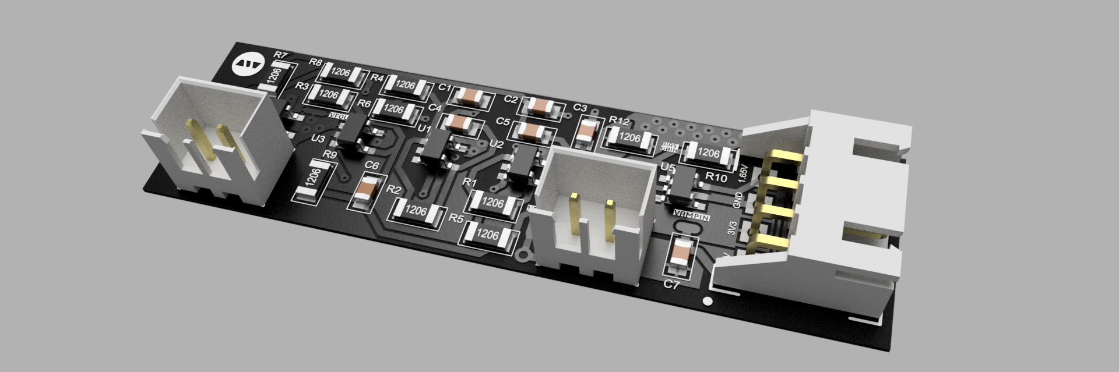
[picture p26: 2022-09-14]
Media/pictures/perspective-3.png

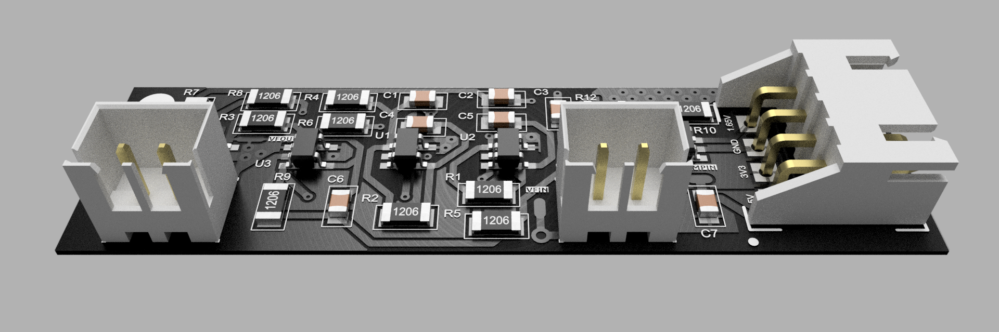
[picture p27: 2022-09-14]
Media/pictures/filter-top-front.png

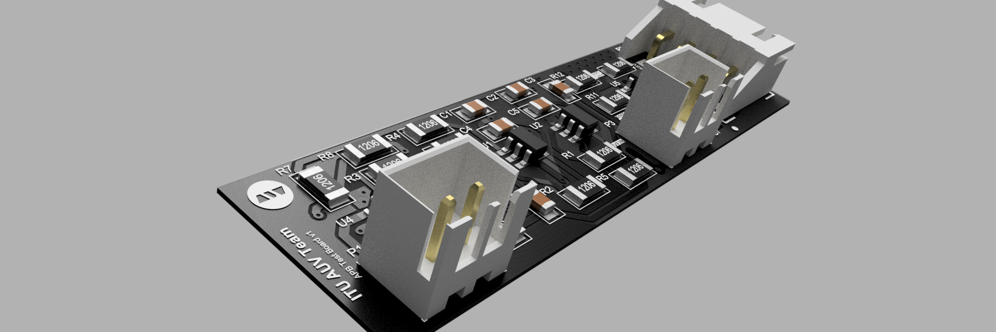
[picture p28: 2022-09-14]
Media/pictures/perspective-2.png

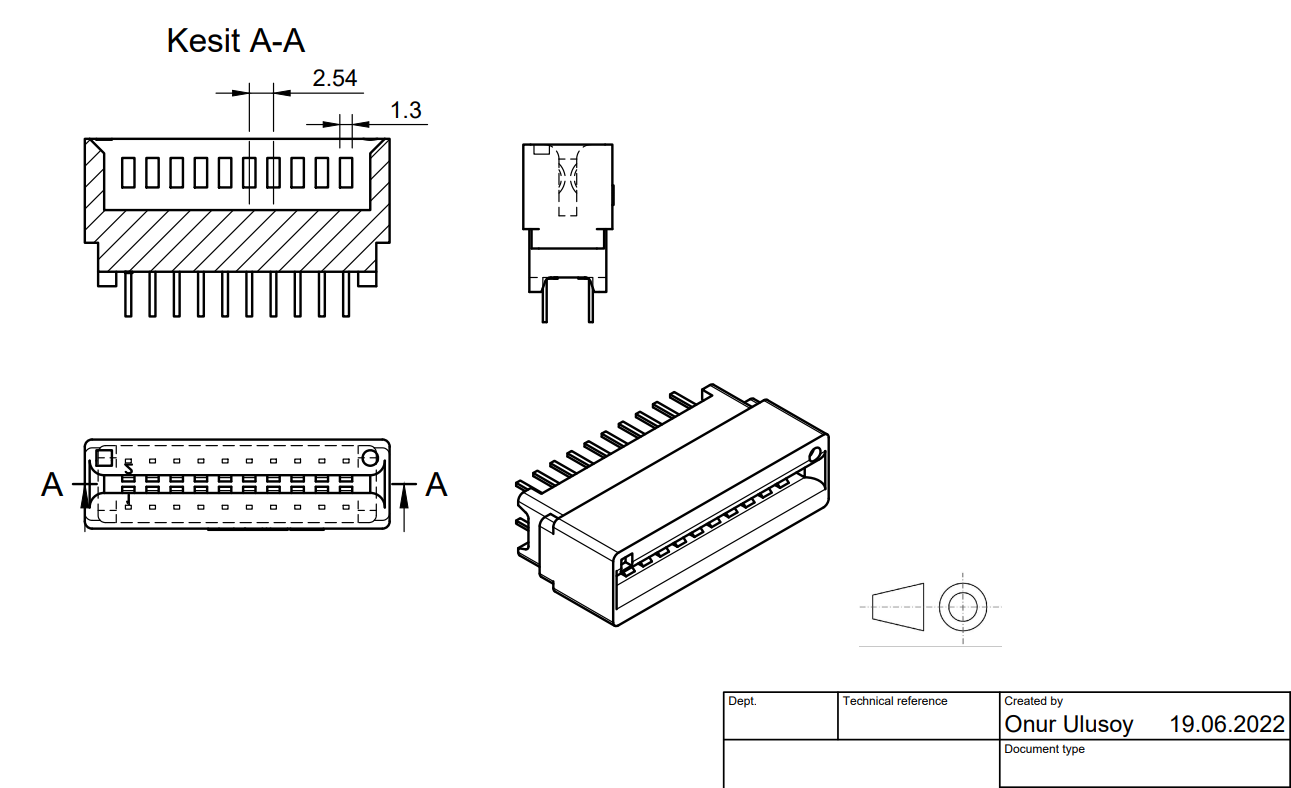
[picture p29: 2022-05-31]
Docs/APB gold fingers edge connector drawing.PNG

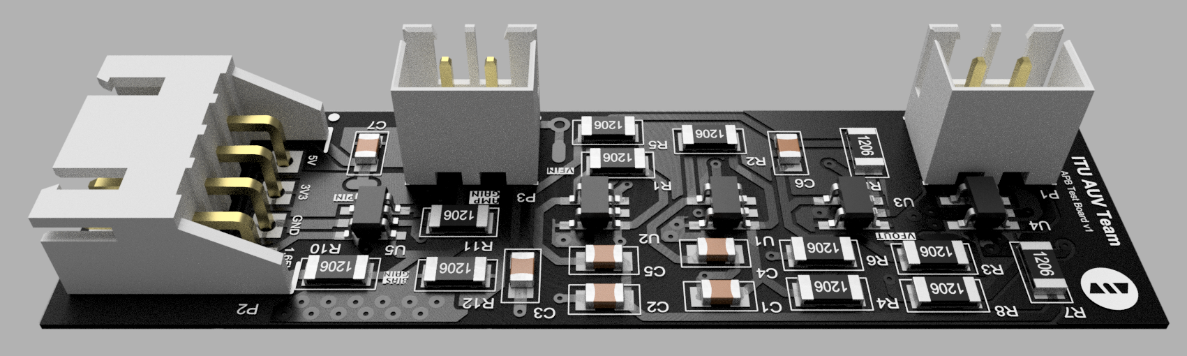
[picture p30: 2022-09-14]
Media/pictures/filter-top-back.png

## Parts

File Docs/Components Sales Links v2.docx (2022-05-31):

1k (Paket: 1206)

Özdisan:

https://ozdisan.com/passive-components/resistors/smt-smd-and-chip-resistors/1206S4F1001T5E

10k (Paket: 1206)

Özdisan:

https://ozdisan.com/passive-components/resistors/smt-smd-and-chip-resistors/1206S4F1002T5E

2k (Paket: 1206)

Özdisan:

https://ozdisan.com/passive-components/resistors/smt-smd-and-chip-resistors/1206S4F2001T5E

Kapasiteler

0.1 uF (Paket: 0805)

https://ozdisan.com/passive-components/capacitors/smt-smd-and-mlcc-capacitors/CL21B104JBCNNNC

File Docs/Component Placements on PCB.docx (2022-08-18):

R6: 28k7

R8: 1k74

R2: 57k6

R4: 18k7

R7: 845

R1: 121k

R5: 25k5

R9: 1k18

R3: 165k

R10: 1k

R11: 10k

R12: 2k

C1-C4: 470p

C2-C5: 360p

C3-C6: 430p

C7: 0.1u

Aşağıdan da bakılabilir dirençlerin numaraları var

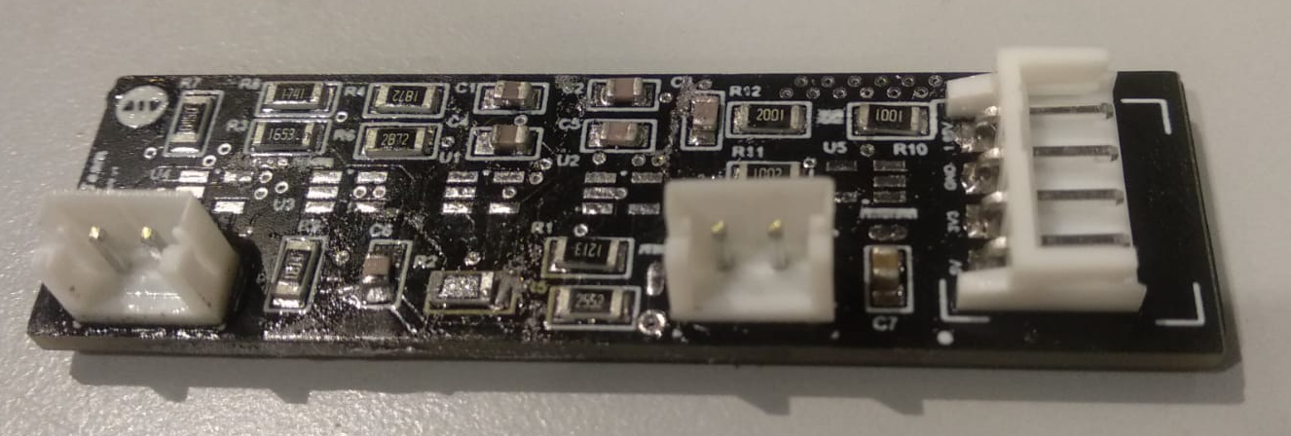
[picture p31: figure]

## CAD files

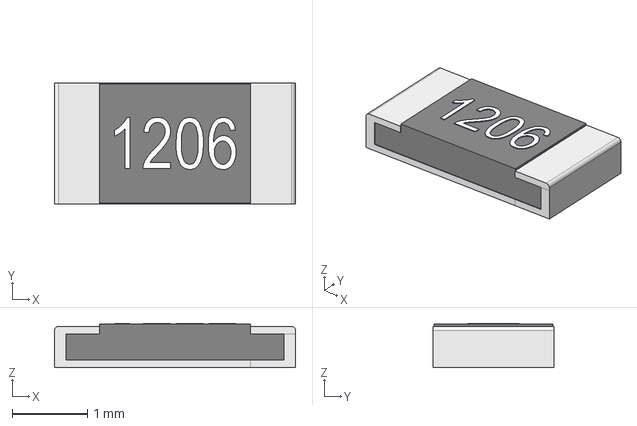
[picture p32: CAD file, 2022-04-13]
3D Models/resistencia_smd_1206 v12.step
3.20 x 1.60 x 0.59 mm

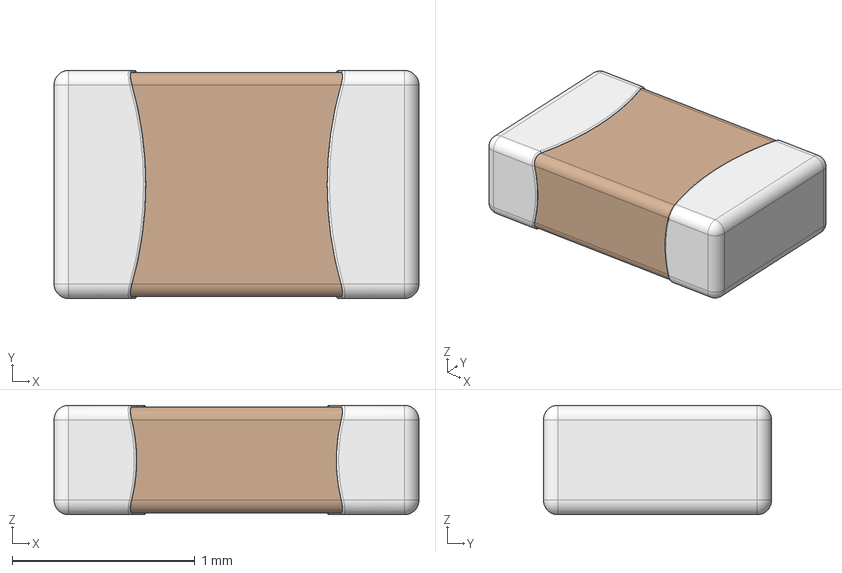
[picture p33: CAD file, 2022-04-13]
3D Models/Ceramic_Capacitor_0805_h24mil v6.step
2.00 x 1.25 x 0.6 mm
Pin1
Pin2
CeramicBody

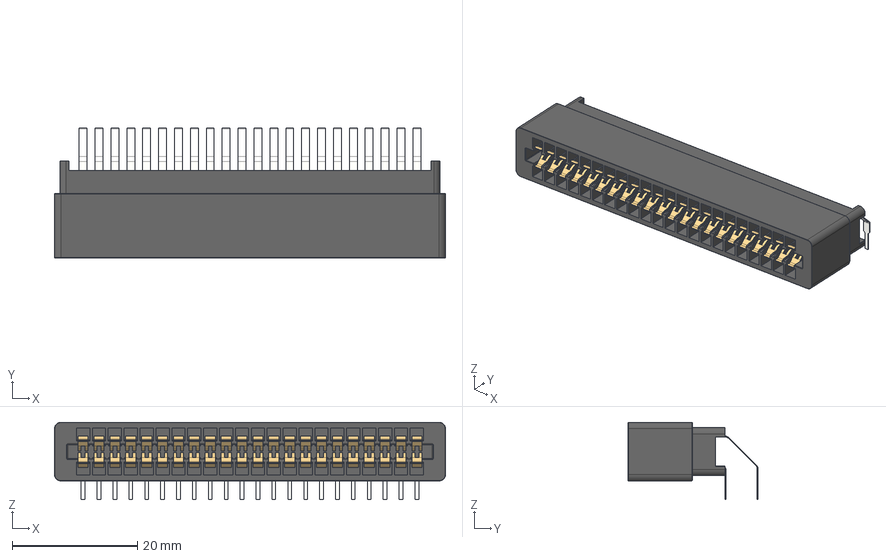
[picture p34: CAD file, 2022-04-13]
3D Models/EDGE PCB Connector P2.54mm 44pin 2 Rows Right Angle v1.step
62.5 x 20.7 x 12.3 mm
EDGE Card Connector 44pos Body
EDGE Connector 2.54mm Contact Right Angle Upper x 22
EDGE Connector 2.54mm Contact Right Angle Lower x 22

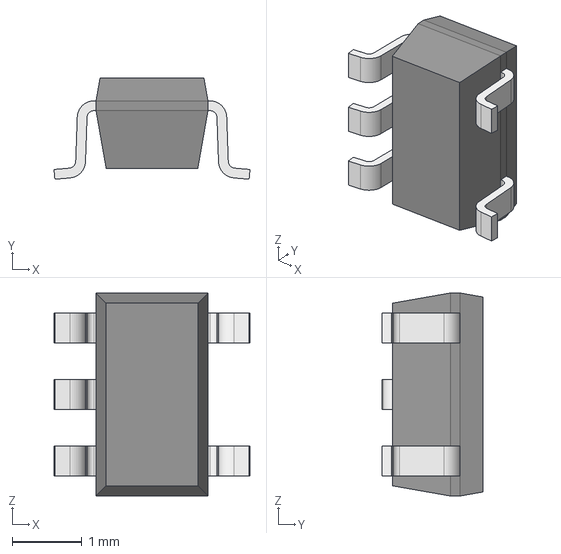
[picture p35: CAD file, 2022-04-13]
3D Models/AD8065ARTZ-REEL7 v1.step
2.80 x 1.45 x 2.90 mm

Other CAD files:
Legacy Designs/Filter Test Design on Eagle/filter-test.f3d

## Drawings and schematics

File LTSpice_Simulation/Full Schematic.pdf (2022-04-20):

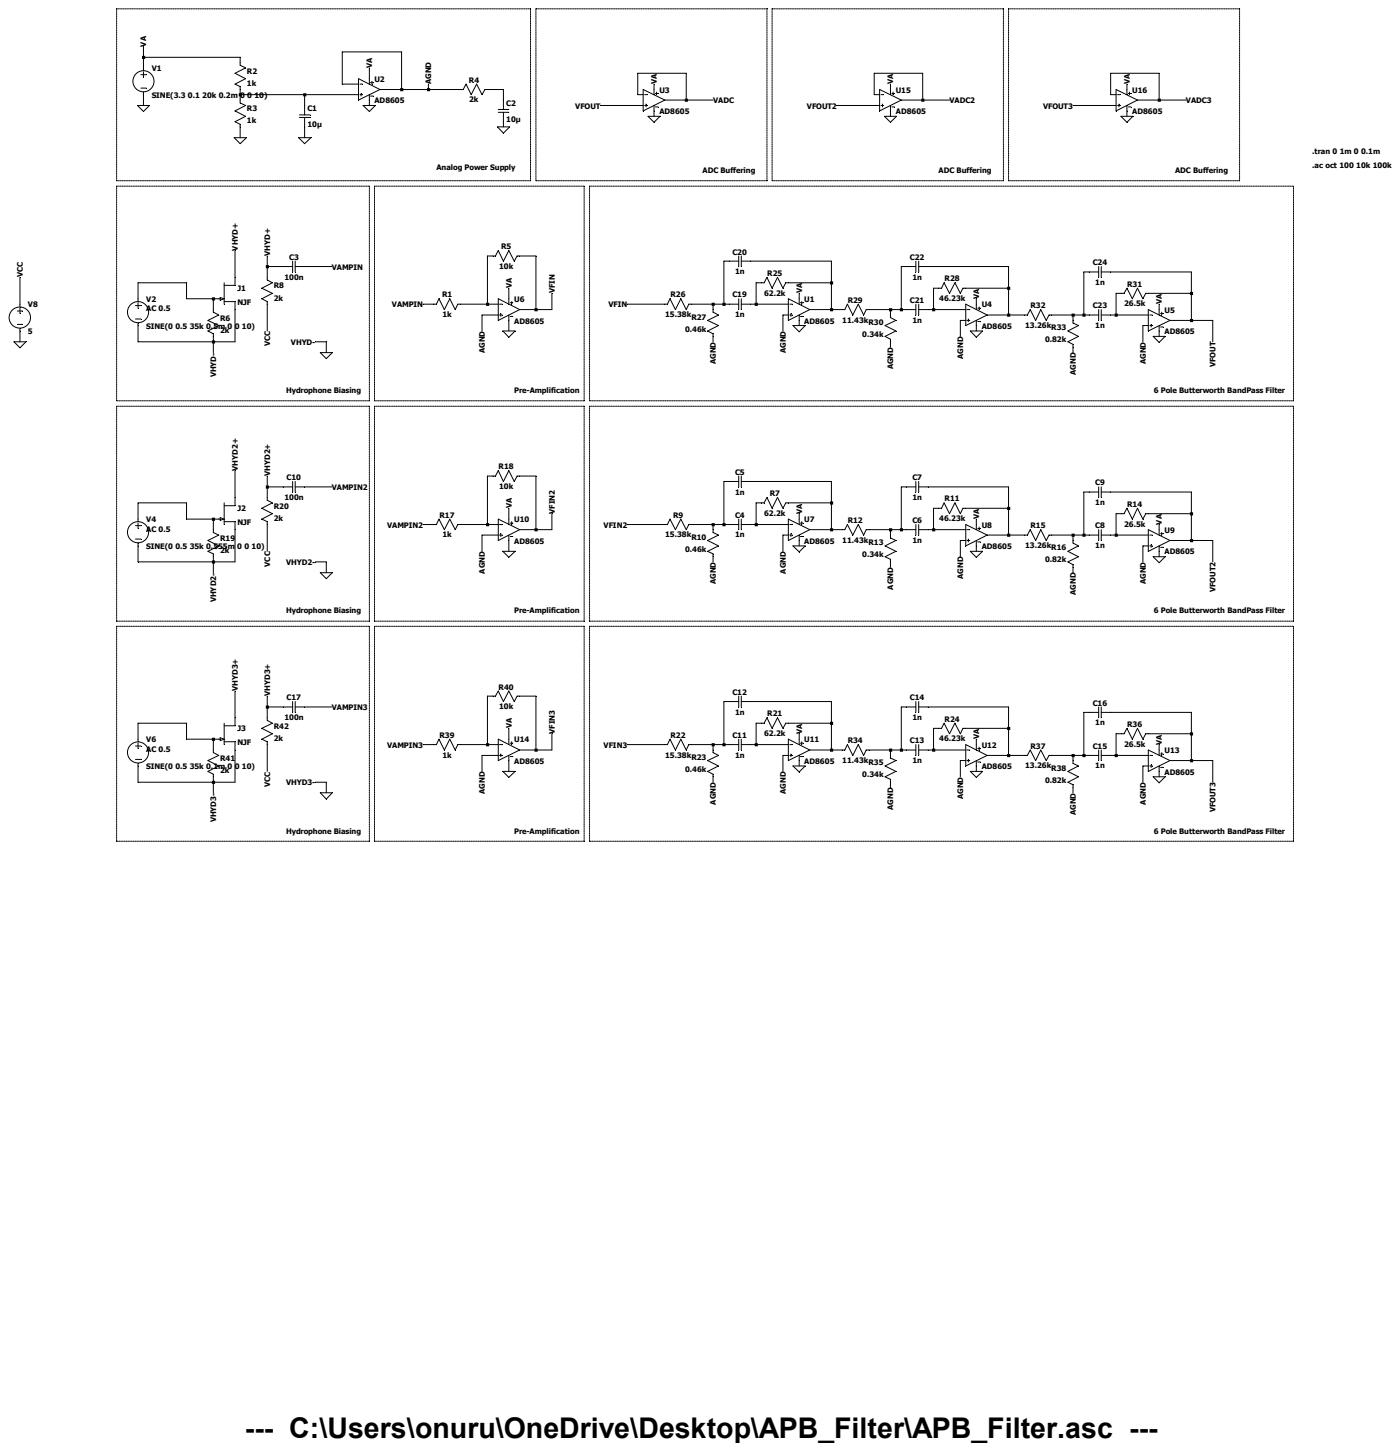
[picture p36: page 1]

Analog Power Supply | 10µ | ADC Buffering | ADC Buffering | ADC Buffering

R5 Pre-Amplification | C20 | 6 Pole Butterworth BandPass Filter

--- C:\Users\onuru\OneDrive\Desktop\APB_Filter\APB_Filter.asc ---

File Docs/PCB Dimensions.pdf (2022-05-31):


Top Layer (Scale 4:1)

Bottom Layer (Scale 4:1)

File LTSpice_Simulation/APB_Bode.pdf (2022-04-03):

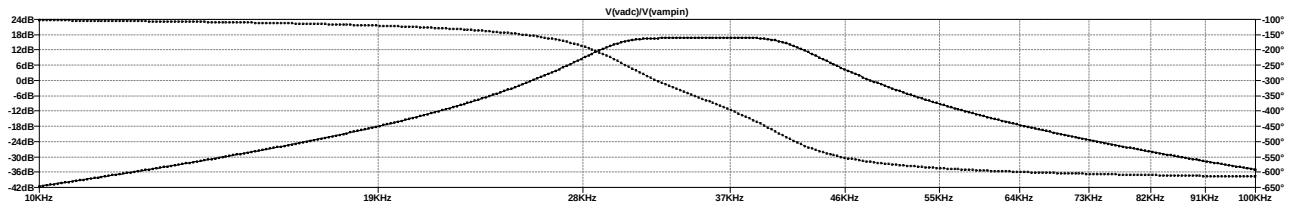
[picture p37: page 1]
10KHz; 19KHz; 28KHz; 37KHz; 46KHz; 55KHz; 64KHz; 73KHz; 82KHz; 91KHz; 100KHz; V(vadc)/V(vampin)

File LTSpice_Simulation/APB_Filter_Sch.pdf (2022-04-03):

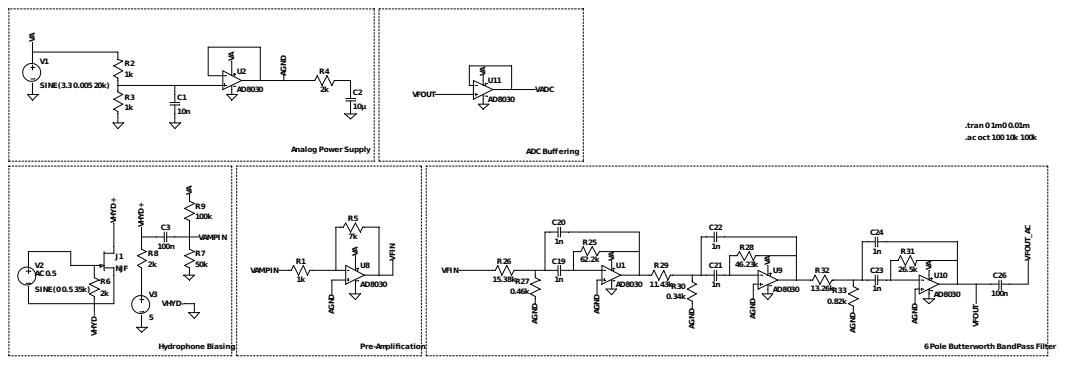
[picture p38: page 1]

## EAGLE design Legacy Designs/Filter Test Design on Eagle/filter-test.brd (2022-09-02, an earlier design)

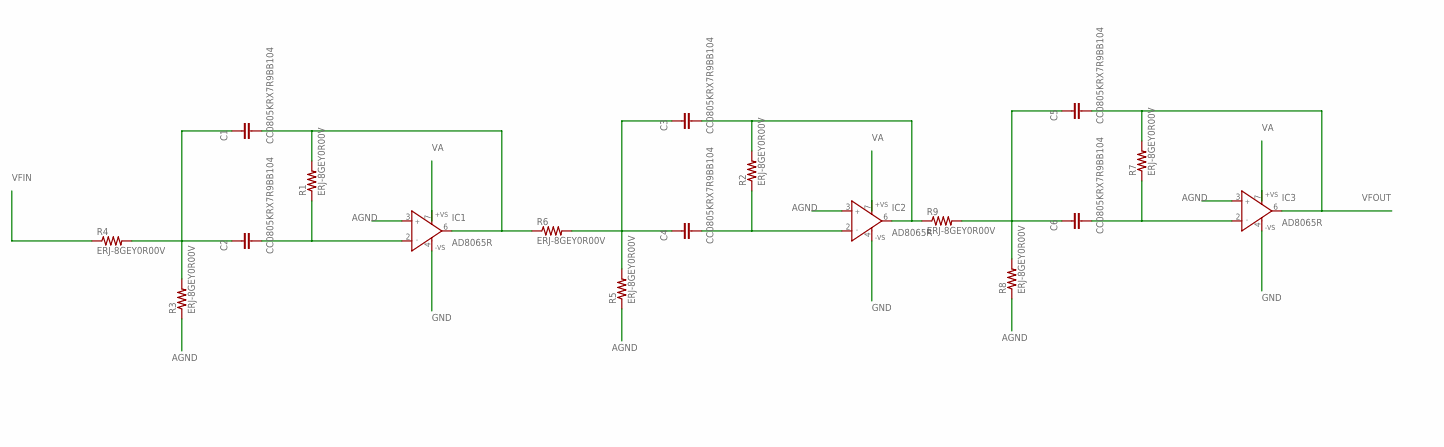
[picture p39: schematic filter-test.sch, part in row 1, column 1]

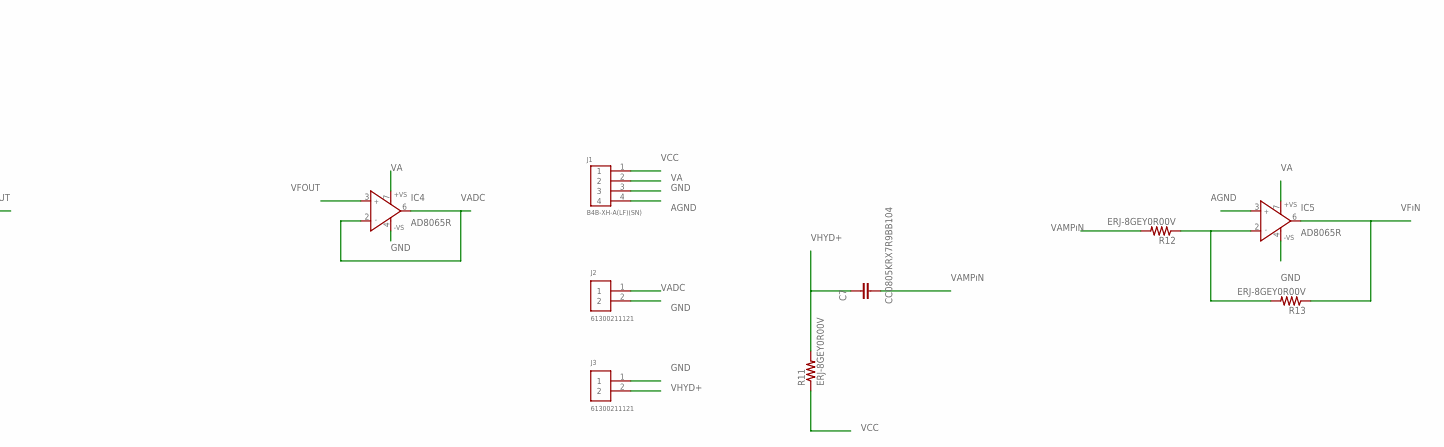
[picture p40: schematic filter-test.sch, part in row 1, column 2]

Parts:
C1, C2, C3, C4, C5, C6, C7: CC0805KRX7R9BB104; CAP_0805
IC1, IC2, IC3, IC4, IC5: AD8065R; SO8
J1: B4B-XH-A(LF)(SN)
J2, J3: 61300211121
R1, R2, R3, R4, R5, R6, R7, R8, R9, R11, R12, R13: ERJ-8GEY0R00V; RES_1206

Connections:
AGND: IC1.3 (IN+), IC2.3 (IN+), IC3.3 (IN+), IC5.3 (IN+), J1.4, R3.1, R5.1, R8.1
GND: IC1.4 (-VS), IC2.4 (-VS), IC3.4 (-VS), IC4.4 (-VS), IC5.4 (-VS), J1.3, J2.2, J3.1
unnamed: C1.1, C2.1, R3.2, R4.2
unnamed: C1.2, IC1.6 (OUT), R1.2, R6.1
unnamed: C2.2, IC1.2 (IN-), R1.1
unnamed: C3.1, C4.1, R5.2, R6.2
unnamed: C3.2, IC2.6 (OUT), R2.2, R9.1
unnamed: C4.2, IC2.2 (IN-), R2.1
unnamed: IC5.2 (IN-), R12.1, R13.2
unnamed: C5.1, C6.1, R8.2, R9.2
unnamed: C6.2, IC3.2 (IN-), R7.1
VA: IC1.7 (+VS), IC2.7 (+VS), IC3.7 (+VS), IC4.7 (+VS), IC5.7 (+VS), J1.2
VADC: IC4.2 (IN-), IC4.6 (OUT), J2.1
VAMPıN: C7.2, R12.2
VCC: J1.1, R11.1
VFIN: R4.1
VFOUT: C5.2, IC3.6 (OUT), IC4.3 (IN+), R7.2
VFıN: IC5.6 (OUT), R13.1
VHYD+: C7.1, J3.2, R11.2

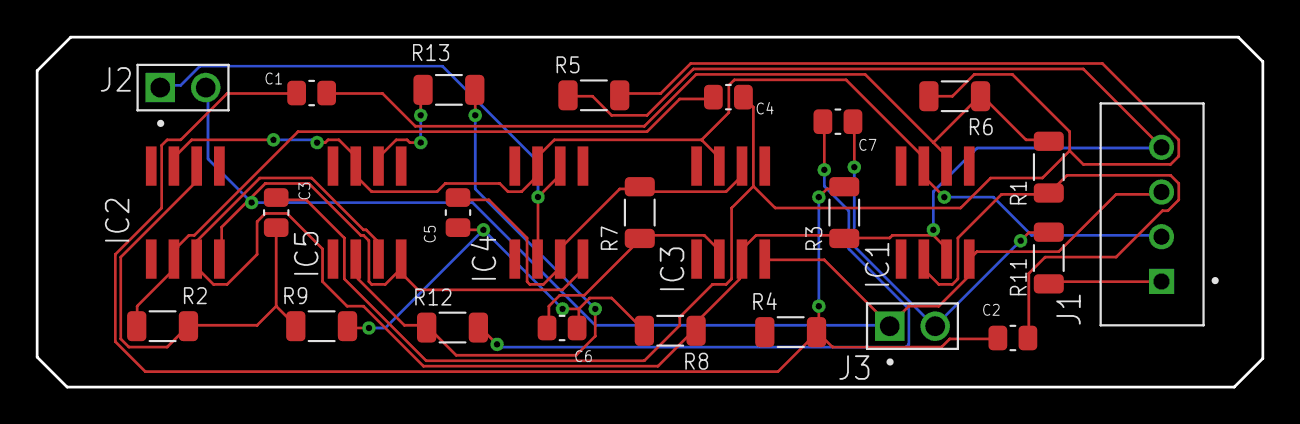
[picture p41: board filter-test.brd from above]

Board: 2 copper layers, 68.5 x 19.6 mm, 27 parts (0 on the bottom side), 18 nets.

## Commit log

2022-04-03 Embed APB_Filter schematic representations
2022-04-07 Integrate operational amplifier for design visualization
    [AD8065ARTZ-REEL7 v1.step]
2022-04-09 Incorporate ceramic capacitor 3D model for design accuracy
    [Ceramic_Capacitor_0805_h24mil v6.step]
2022-04-11 Add PCB connector 3D model for enhanced layout comprehension
    [EDGE PCB Connector P2.54mm 44pin 2 Rows Right Angle v1.step]
2022-04-13 Store APB filter ASC implementation
2022-04-13 Include SMD resistor 3D model for detailed design visualization
    [resistencia_smd_1206 v12.step]
2022-04-15 Initialize pcblib with operational amplifier AD8065ARTZ-REEL7
2022-04-16 Log APB filter operations
2022-04-17 Add MLCC CAP 0805_2012 RF to the PCB library
2022-04-18 Commit APB filter raw operational file
2022-04-19 Incorporate MLCC CAP 1206_3216 - 0.8MM into the PCB library
2022-04-20 Consolidate full schematic in PDF format
2022-04-21 Expand PCB library with RES 0805_2012 resistor
2022-04-23 Include RES 1206_3216 RF resistor to the PCB library
2022-04-25 Integrate TO92127P478H483-3 into the PCB library
2022-04-29 Incorporate 2N3819 into schematic library
2022-05-01 Add AD8065ARTZ-REEL7 to schematic library for design consistency
2022-05-05 Initiate schematics with 6 Pole Butterworth Bandpass Filter
    [6 Pole Butterworth Bandpass Filter.SchDoc]
2022-05-07 Embed input-output connection schematic for clear representation
    [Input-Output.SchDoc]
2022-05-09 Extend ADC Buffering schematic for precise analog-to-digital conversion
    [ADC Buffering.SchDoc]
2022-05-11 Establish APB Filter Test Board project for PCB design
    [APB_Filter_Test_Board.PrjPcb]
2022-05-13 Initiate PCB Document for APB Filter Test Board design
    [APB_Filter_Test_Board.PcbDoc]
2022-05-15 Provide PCB Design Flow (PCBDwf) for APB Filter Test Board
2022-05-17 Conclude APB Filter Test Board design process with OutJob
2022-05-21 Include APB gold fingers edge connector drawing for reference
2022-05-27 Integrate EDGE PCB Connector P2.54mm 44pin 2 Rows Right Angle Drawing
2022-05-29 Incorporate PCB Dimensions for clear visualization and manufacturing
2022-05-31 Provide Schematic Sheets-BOM for circuit realization
2022-06-06 Append Version1 Gerber Files for PCB manufacturing
    [Assembly Testpoint Report for PCB1.csv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]
2022-08-21 Attach comprehensive PCB design information
2022-08-23 Add Legacy APB Design 2021 files for reference
    [hp_main.SchDoc]
2022-09-01 Add filter-test schematic from Eagle legacy design
    [filter-test.sch]
2022-09-02 Add filter-test board design from Eagle legacy
    [filter-test.brd]
2022-09-03 Append 3D model and render from Eagle legacy design
    [filter-test.f3d]
2022-09-09 Write simulation and PCB parts
2022-09-09 Complete PCB explanations
2022-09-11 Write project time line and gallery parts, add turnable html for pcb
